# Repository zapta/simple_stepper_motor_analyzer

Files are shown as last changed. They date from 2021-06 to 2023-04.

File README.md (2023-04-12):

# Simple Stepper Motor Analyzer

**NOTE:** (April 2023) A new design of a stepper motor analyzer is available at 
https://github.com/zapta/ble_stepper_motor_analyzer. The new design has similar capabilities to this one but uses a Bluetooth link and a Mac/Windows/Linux app to display the data in real time. It is also less expensive to produce and can be ordered fully assembled from JLCPCB SMD service. You can embed one or more of the new analyzers in your 3D printer and connect to them remotely whever you want.

**NOTE:** (Aug 2022) A variant of the Simple Stepper Motor Analyzer can be purchased in Japan at 
https://nyarurato.booth.pm/items/4025304 . International shipping is also available.

**IMPORTANT:** We are not associated with any seller nor do we have any experience with their products
which may or may not differ from the design here. The Simple Stepper Motor Analyzer is an *as-is*
open source design for educational purposes and people may chose to use it on their own risk.

&nbsp;

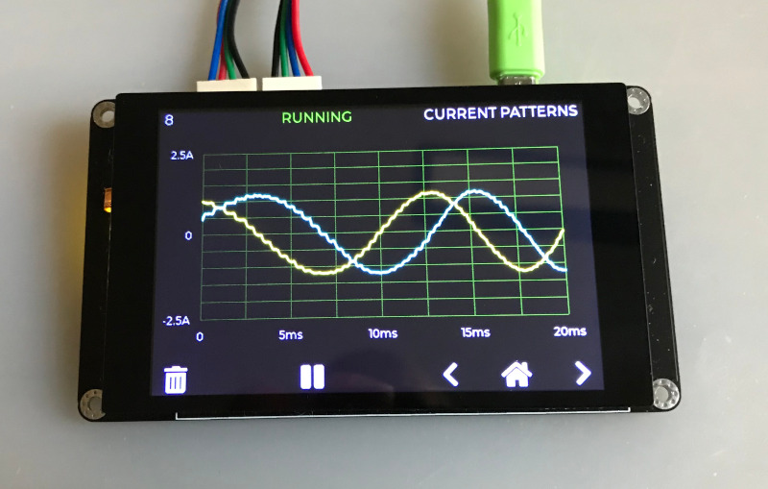
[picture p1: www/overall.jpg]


&nbsp;

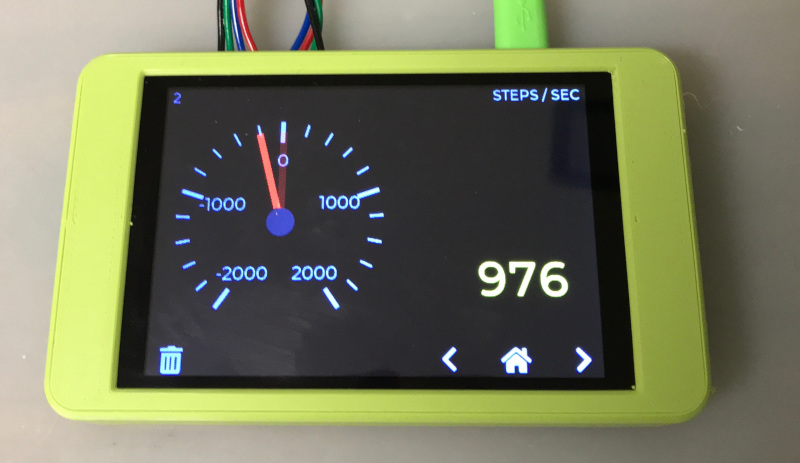
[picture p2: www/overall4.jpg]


&nbsp;

## Demonstration

Michael from the Teaching Tech youtube channel made [a great video explaining how stepper motors work](https://youtu.be/4iII25DGIdA) and used the Simple Stepper Motor Analyzer for some of the demonstrations. 

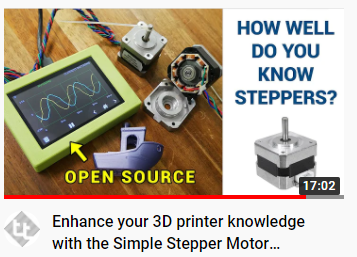
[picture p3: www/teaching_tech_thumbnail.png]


&nbsp;

## Highlights
* Low cost and minimalist DYI hardware design.
* Standalone. Doesn't require a computer to operate.
* Analyzes the stepper motor signals in the actual system (e.g. a 3D printer).
* Galvanically isolated current sensors. Does not interfere with the operating equipment, even when its turned off.
* Easy to connect using a pair 4 wire pass through connectors.
* Intuitive user interface with color display and a capacitive touch.
* Microstepping resolution of 1% of a full step.
* Provides momentary readings, signal patterns, and statistical measurements.
* Hardware and software are open sourced with a generous license.
* Based on free tools (Kicad, platformio, LVGL) and the Raspberry Pi Pico.
* Can be easily customized (new featured, cost reduction, data link to a computer, etc).
* Powered 5VDC, 200ma via a USB-C connector.

## Overview
Diagnosing the operation of stepper motor in 3D printers and CNC machines used to require stepper motor analyzers that costs thousands of dollar. Not anymore! The Simple Stepper Analyzer ('Analyzer' in short) brings these capabilities to every maker for a tiny fraction of the price and with a minimalist DIY electronic design that leaves the heavy lifting to the firmware.

The Analyzer is self contained, has two 4-wires pass-through connectors connecting the stepper motor, is powered from a common 5V charger with a micro USB cable, provides a simple to use graphical user interface with a 3.5" color touch screen, and provides a plethora of stepper motor measurements.

The Analyzer is provided to the community as a public domain reference design that can be built and used as is, or be customized with additional features or for a lower cost as desired. The hardware and firmware come with a liberal open source license (CC0) that allows commercial usages and doesn't require code source code sharing.

---
## Disclaimer
THE DESIGN IS PROVIDED "AS IS", WITHOUT WARRANTY OF ANY KIND, EXPRESS OR IMPLIED, INCLUDING BUT NOT LIMITED TO THE WARRANTIES OF MERCHANTABILITY, FITNESS FOR A PARTICULAR PURPOSE AND NONINFRINGEMENT. IN NO EVENT SHALL THE AUTHORS OR COPYRIGHT HOLDERS BE LIABLE FOR ANY CLAIM, DAMAGES OR OTHER LIABILITY, WHETHER IN AN ACTION OF CONTRACT, TORT OR OTHERWISE, ARISING FROM, OUT OF OR IN CONNECTION WITH THE DESIGN OR THE USE OR OTHER DEALINGS IN THE DESIGN.

---
## How does it work?
The principle of operation is very simple, and so is the hardware design. The stepper motor is connected via 4 wire pass-though connectors that allow the Analyzer to monitor the current through the stepper's coils. The Analyzer's user low impedance current sensors that are galvanically isolated such does not interfere with the operation of the 3D printer or other equipment it monitors. The Analyzer measures the coils currents 100k times a second and uses firmware that analyzes the data, extracts the desired measurements, and present them on the screen. For example, this is how an analysis of the distribution of distance by speed distribution looks like:

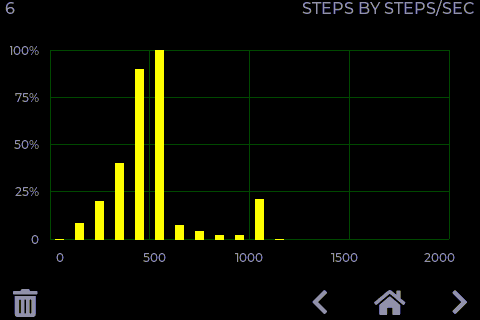
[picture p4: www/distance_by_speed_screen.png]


---
## Operation is simple and intuitive

1. Turn off power to the equipment (e.g. 3D printer).
2. Disconnect the 4 wires of the stepper motor and connect them through the Analyzer two pass through connectors.
3. Power the analyzer using a 5V charger and a micro USB cable.
4. Turn on the equipment and get the stepper going.
5. Use the Analyzer's screen to view the measurements you want.

**NOTE:** The two pass-through connectors of the Analyzer are symmetric and  each can act as an input or output. 

**CAUTION:** Always connect and disconnect stepper motors when their controller is not energized, to reduce the risk of damage to the controller due to high voltage spikes. The analyser itself is not subject to that risk since its uses galvanically isolated current sensors.

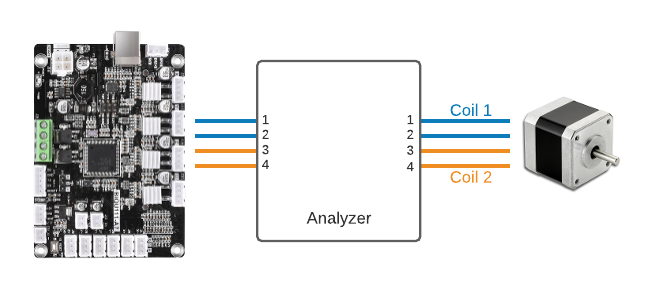
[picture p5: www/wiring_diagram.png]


**NOTE:** The only requirement for proper wiring is that the two wires of one coil should go through pins pair 1,2 and the two wires of the other coil should go through pin pair 3,4. The Analyzer doesn't care about the +/- polarity of the wires in each pair, nor does it care which of the two pass-through connectors is on the controller side and which one is on the stepper side.

**TRIVIA:**: The pin-out and the connector type of the Analyzer follows the Duet3D conventions, except that is uses right angle connector to save space.

---
## The Home Page
The Home page is first page shown when the Analyzer is powered on. It provides summary information as well as access to the Settings page.

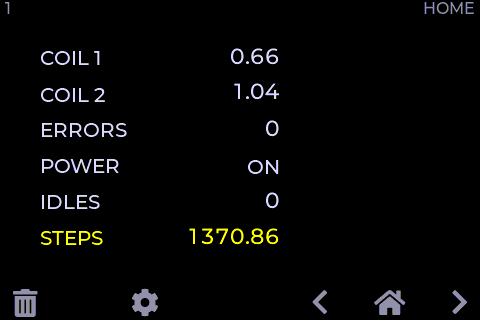
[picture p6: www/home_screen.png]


&nbsp;

#### Page Data

Field | Description
:------------ | :-------------
 COIL&nbsp;1 | Momentary coil 1 current in Amps.
 COIL&nbsp;2 | Momentary coil 2 current in Amps.
 ERRORS | The number of phase errors detected so far. Phase errors happens when the current patterns are so distorted that a forward/backward movement cannot be determined.
 POWER | Indicates if the stepper motor is currently energized. This is determined by the sum of currents in they two coils.
 IDLES | The number of times that stepper motor change status from energized to non energized.
 STEPS | The distance the stepper moved so far. Each full step forward increments this value by one and each full step backward decrements it by one. When the stepper motor is energized, the display also shows fractional steps in resolution of 1/100th of a full step.

HINT: The fractional step value cannot be reset because it is derived from the momentary currents in the two coils. Only the stepper motor driver can reset the fraction by positioning the stepper motor on an exact full step.

HINT: To swap forward/backward directions of the Analyzer use the Settings page. This does not affect the stepper motor itself.

&nbsp;
#### Page Actions

Action | Description
:------------: | :-------------
 | Clear all data.
 | Open the Settings page.

&nbsp;

---

## The Settings Page

This is a special page that is accessible from the Home page and allows to calibrate the Analyzer. The settings are stored in a non volatile memory and are preserved when the Analyzer is turned off.

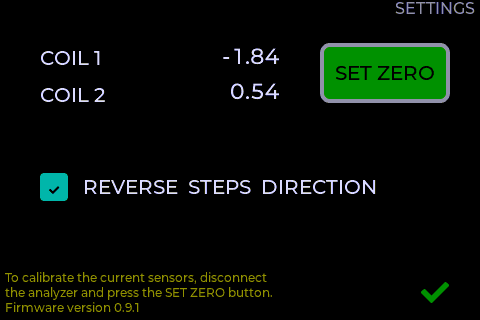
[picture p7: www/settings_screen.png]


&nbsp;
#### Page Data

Data | Description
:------------: | :-------------
COIL&nbsp;1 | The momentary current of stepper coil 1 in Amp units. Should be zero, or very close to zero, when the stepper motor is disconnected.
COIL&nbsp;2 | The momentary current of stepper coil 2 in Amp units. Should be zero, or very close to zero, when the stepper motor is disconnected.

&nbsp;
#### Page Actions

Action | Description
:------------: | :-------------
SET ZERO | Used to calibrate the zero reading of the current sensors. To do so, Disconnect the stepper motor and press this button.
REVERSE STEPS DIRECTION | Changes the forward/backward step directions of the Analyzer. Does not affect the stepper motor itself. Having the correct direction is important for measurements such as the Retraction analysis.
 | Press exist the Settings page.

&nbsp;

---

## The Speed Dial Page

This page measure the stepper speed in units of full steps per second. 

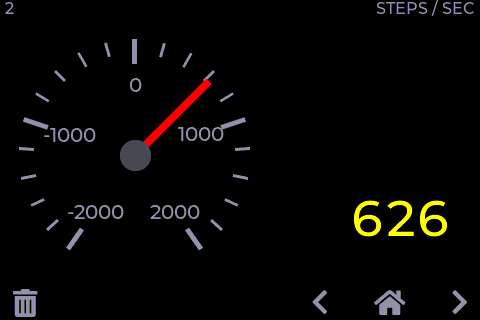
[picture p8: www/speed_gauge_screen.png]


&nbsp;
#### Page Data

Data | Description
:------------ | :-------------
Speed&nbsp;Dial | The speed dial shows the momentary stepper speed in full steps per second units. Forward speed is on the right side and backward speed is on the left.
Speed&nbsp;Value | This field shows the speed in a numeric form. IT is updated less frequently than the dial to allow easy reading.

&nbsp;
**HINT:** The Settings page allows to swap the forward/backward directions.

&nbsp;
#### Page Actions

Action | Description
:------------: | :-------------
 | Clears all data.
Tap the dial |Toggles the dial's speed range.

&nbsp;

---

## The Distance Graph Page

This page shows scrolling graph with the total number of full steps vs. time.

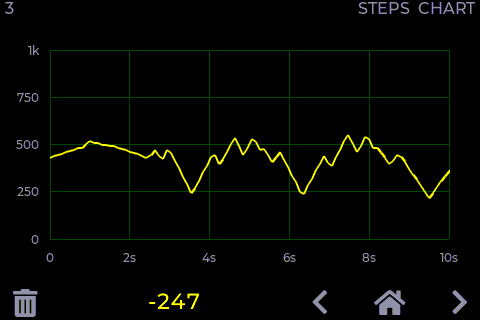
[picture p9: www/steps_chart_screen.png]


&nbsp;

#### Page Data

Data | Description
:------------ | :-------------
Distance&nbsp;Graph | This graph shows how the distance, in units of full steps, changes over time.
Distance&nbsp;value | The numeric value of the distance in full steps.  This fields is identical to the STEPS field in the Home page.

&nbsp;

#### Page Actions

Action | Description
:------------: | :-------------
 | Clears all data.
Tap the graph | Toggles the range of the vertical axis.

&nbsp;

---

#### The Retraction Graph Page

This page is useful to analyze the retraction in of 3D printer extruder.

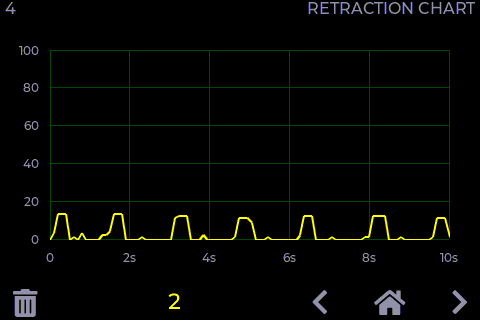
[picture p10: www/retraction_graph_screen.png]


&nbsp;
**TRIVIA:** The graph above was taken while testing a direct extruder printer with [Thing #909901](https://www.thingiverse.com/thing:909901).
&nbsp;
#### Page Data

Data | Description
:------------ | :-------------
Retraction&nbsp;Graph | This graphs tracks the retraction of 3D extruder full step units.  Retraction is defined as the filament length that was inside the extruder and is now retracted outside of the extruder. 
Retraction value |  This field shows the current retraction level in a numeric form.

&nbsp;
#### Page Actions

Action | Description
:------------: | :-------------
 | Clear all data.
Tap the graph | Changes the range of the vertical axis.

&nbsp;

---

## The Time by Speed Page

This page shows an histogram with the distributing of time by stepper speed. That is how much time was spent in each speed range. The values are normalized such that the longest bar is always at 100%.

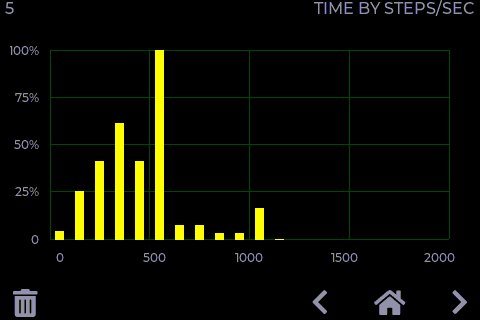
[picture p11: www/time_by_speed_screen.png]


&nbsp;
#### Page Data

Data | Description
:------------ | :-------------
Time&nbsp;Histogram | The horizontal axis indicates speed in full steps per second units. The height of each bar indicate the time of all steps in that speed range, with the length of the longest bar normalized to 100%.

&nbsp;
#### Page Actions

Action | Description
:------------: | :-------------
 | Clear all data.

&nbsp;

---

## The Distance by Speed Page

This page shows an histogram with the the distribution of distance by stepper speed.



&nbsp;
#### Page Data

Data | Description
:------------ | :-------------
Distance&nbsp;Histogram |  The horizontal axis indicates speed in full steps per second units. The height of each bar indicate the distance or number of steps in that speed range, with the length of the longest bar normalized to 100%.

&nbsp;
#### Page Actions

Action | Description
:------------: | :-------------
 | Clear all data.

&nbsp;

---

## The Current by Speed Page

This page measures the ability of the stepper motor's controller to maintain peak current at high speeds.

The screenshot below shows a healthy system where the peak current is virtually flat across the speed range.

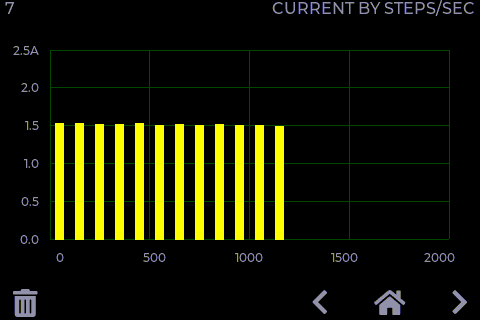
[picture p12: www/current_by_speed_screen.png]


The screenshot below shows a system that is not capable to maintain peak current and starves the stepper motor at high speeds, resulting in poor torque and possible skipped steps.

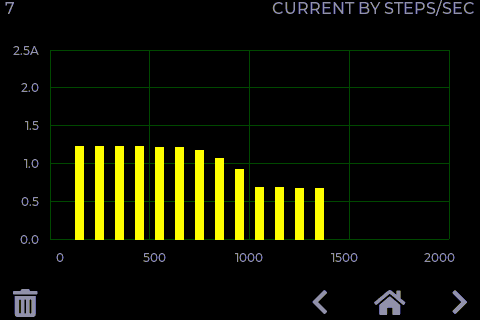
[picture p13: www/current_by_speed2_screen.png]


&nbsp;
#### Page Data

Data | Description
:------------ | :-------------
Peak&nbsp;Current&nbsp;Histogram | The horizontal axis indicates speed in full steps per second units. The height of each bar indicates the average peak current in Amps of  steps that speed range. 

&nbsp;
#### Page Actions

Action | Description
:------------: | :-------------
 | Clear all data.

&nbsp;

---

## Coil Current Patterns Page

This page shows the current patterns in the two stepper coils.

The screenshot below shows a healthy system where the signals are nice and clean and reaches the target peak current.

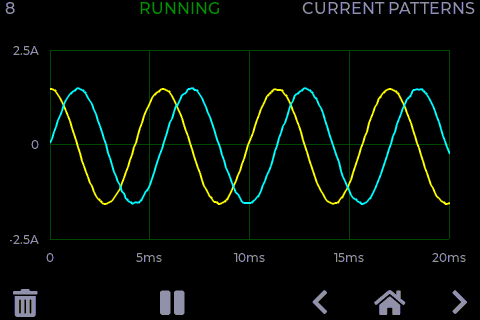
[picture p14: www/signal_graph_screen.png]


&nbsp;

The screenshot below is from a poor system where high speed results in distorted and insufficient current, resulting in loss of torque and a potential for skipped steps.

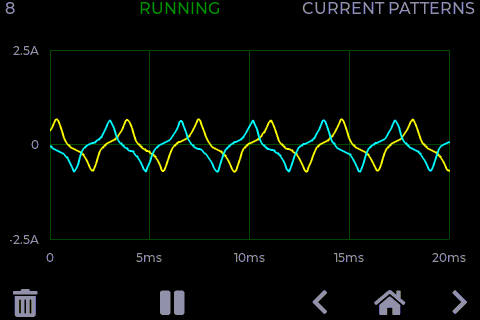
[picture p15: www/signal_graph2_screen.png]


&nbsp;

**GENERAL INFORMATION:** Each cycle of the stepper current pattern represent 4 full steps. The centers of those steps are at on the four vertical dotted lines where the currents of the two coils are identical, in the same or in  opposite polarities. The transitions between the steps are on the 4 vertical solid lines where one of the coils is at zero current. This cycle of 4 full steps is sometimes referred to as a single 'electric rotation'. The analyzer computes the exact phase on this cycle using the standard trigonometric function atan2(current1, current2) which can also be calculated manually from the current readings in the Home page.

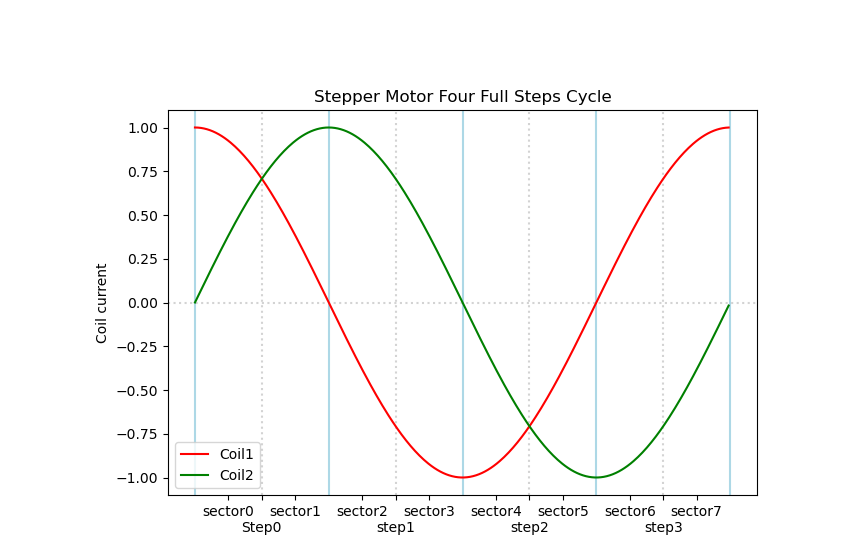
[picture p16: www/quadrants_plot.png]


&nbsp;

#### Page Data

Data | Description
:------------ | :-------------
Current&nbsp;graph | The horizontal axis indicates time in milliseconds. The vertical axis indicate coil current level in Amps. The two graphs show the current patterns of the respective stepper coils.

**NOTE:** The graph is updated only when sufficient stepper motor movement is detected.

&nbsp;
#### Page Actions

Action | Description
:------------: | :-------------
 | Clear all data.
 | When running, pauses the display updates.
 | When paused, resume the display updates.
Tap the graph | This toggles the range of the horizontal axis.

&nbsp;

---

## Coil Current Phase Page

This page draws the current patterns of the two coils as a [Lissajous curve](https://en.wikipedia.org/wiki/Lissajous_curve) which allows to examine visually distortions such as non sinusoidal current, phase distortion, and reduced amplitude.

In an ideal system, the graph is a perfect smooth circle, that doesn't change its size when the stepper's speed changes. Patterns that significantly diverge from that indicates a sub optimal configuration and operation.

Following picture shows a pattern from a well functioning system. The graph is round, reasonable smooth, and has sufficient size which indicates good current drive. 

The horizontal axis indicates the coil 1 current and the vertical axis indicates coil 2 current. In this example, both span nicely between -2A to +2A.

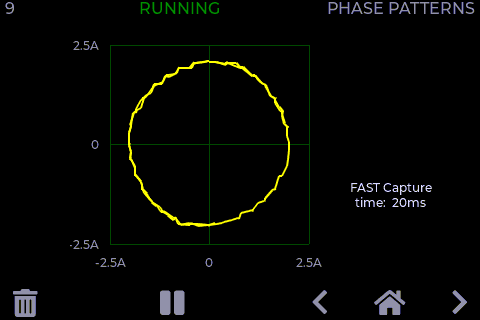
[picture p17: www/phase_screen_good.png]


&nbsp;

The screenshot below is from a poor system where high speed results in distorted and insufficient current, resulting in loss of torque and a potential for skipped steps. The pattern is far from a clean circle and the shape has reduced size.

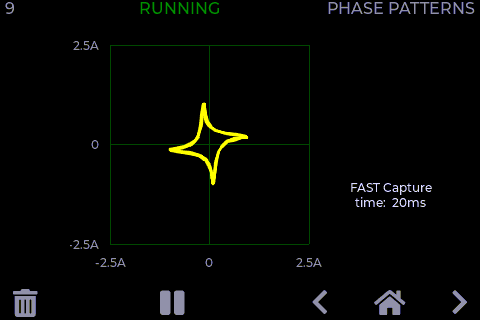
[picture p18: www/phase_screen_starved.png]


&nbsp;

The screenshot below shows a sub optimal operation where a a speed increase of the stepper results in small (less current and torque) and even more distorted curve.

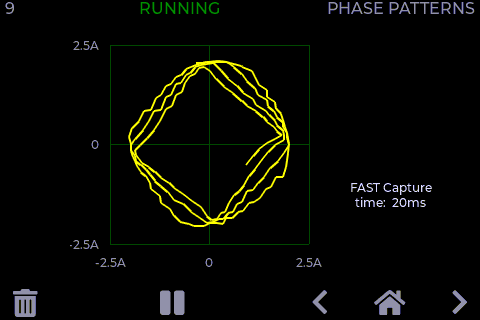
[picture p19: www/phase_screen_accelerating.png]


&nbsp;

The screenshot below shows a well functioning system. The smaller size of the circle compare to the example above indicates that it operates on lower current.

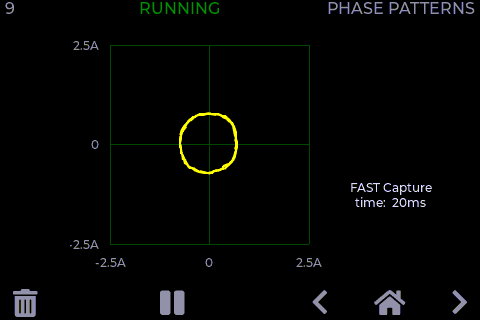
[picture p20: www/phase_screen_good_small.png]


&nbsp;

The screenshot below show an operation of a stepper in full steps mode. The dimension of the pattern indicate good current feed, and the square  shape is the best a full step driver can deliver.

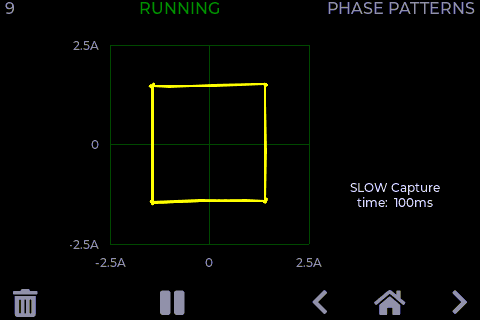
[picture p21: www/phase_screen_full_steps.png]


&nbsp;

The screenshot below show an operation of a stepper in half steps mode. The dimension of the pattern indicate good current feed, and the shape is somewhere between the square shape of full step mode and the round shape of micro stepping interpolation mode.

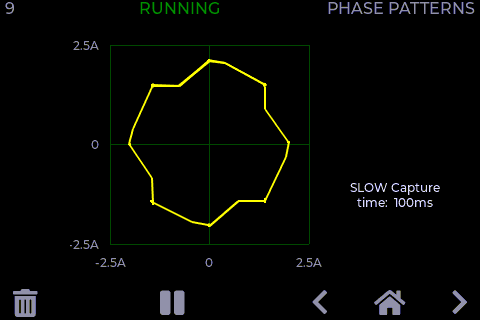
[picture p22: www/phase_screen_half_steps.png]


&nbsp;

#### Page Data

Data | Description
:------------ | :-------------
Lissajous&nbsp;curve | A Lissajous curve drawn from the current pattern of coil 1 (x) and coil2(y). 
Capture speed | Shows the signal capture time. Fast mode works better with fast moving steppers and slow mode works with slow moving steppers. Tap the graph to toggle.

**NOTES** 
* The graph is updated only when sufficient stepper motor movement is detected.
* To view the current pattern that resulted in the current phase pattern, use the navigation button to switch the current patters page, and vice versa.

&nbsp;
#### Page Actions

Action | Description
:------------: | :-------------
 | Clear all data.
 | When running, pauses the display updates.
 | When paused, resume the display updates.
Tap the graph | This toggles the capture time between fast and slow speeds.

&nbsp;

---

## Reference Design Specification

Item | Specification
:------------ | :------------- 
Power consumption | 5V, 175ma.
Power connector | micro USB
MCU | Raspberry Pi RP2040 (Pico module).
Flashing | Drag and drop to a virtual disk.
Data link | USB/Serial link available but not used.
Current measurement | +/-2.5A per coil. (+/-5A sensors optional).
PCB | 102mm x 57mm, two layers
Enclosure | 3D printed, 108.4mm x 63.4mm x 16.6mm
Display | 3.5" 480 x 320, Color, Landscape mode.
Touch screen | Capacitive
Sensor isolation | See ACS70331 data sheet
Sampling rate | 100Khz per channel.
Sampling resolution | 12bits
Current accuracy | estimated at +/- 1%
Max step rate | Software dependent. Currently 2K full steps/sec.
Step resolution | 1/100th of a full step.
User settings storage | On board FLASH.
GUI framework | LVGL library. R3G3B2 color depth.
Programming language | C++
Programming IDE | VSCode, Platformio, WizIO.
Electronic design software | Kicad.
Mechanical design software | Onshape. 

&nbsp;

---

## I want to build me one

The electronic schematic, PCB layout, gerber files, and the firmware source files and released binary are all available on this github repository.

[Schematic](./kicad/stepper_analyzer.pdf)

[Production files](./kicad/JLCPCB)

[BOM](./kicad/BOM.xlsx)

&nbsp;

**Instructions:** Order the PCB with JLCPB with SMD service (see JLCPCB directory with gerbers and bom and pos files). Attach the Pico with XFasten tape and solder. Cut the bottom pins of the KF2510 connectors to 1mm length and solder from the top of the PCB only. Solder the current sensors, attach the TFT to the back of the PCB with XFasten tape and carefully connect the two FPC cables. Program the Pico by connecting it to a computer while it's bootsel button is pressed and drag he uf2 release file to the virtual disk you will see on your computer.

Note: The two servo connectors may be hard to insert and remove due to a small bump on the male side that is intended to lock in place the female connector. If you are handy with X-Acto knife, you can try carefully scraping that bump for easier insertion as I did (knives are sharp and may be dangarous, use proper precautions). 

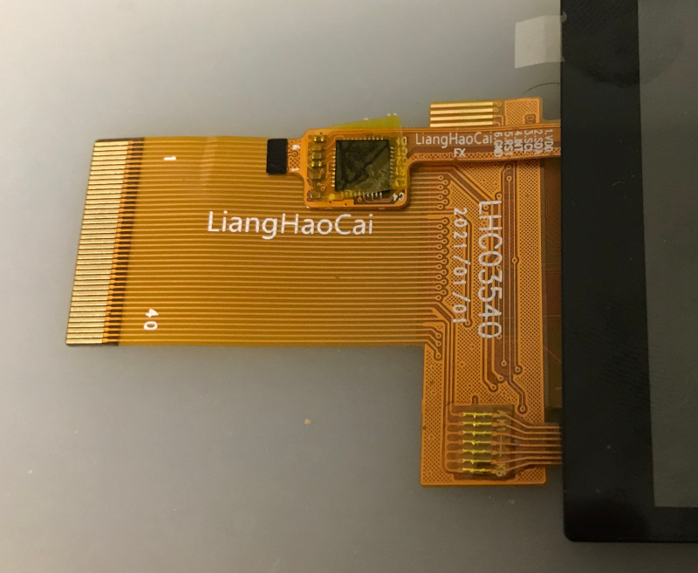
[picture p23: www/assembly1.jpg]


&nbsp;

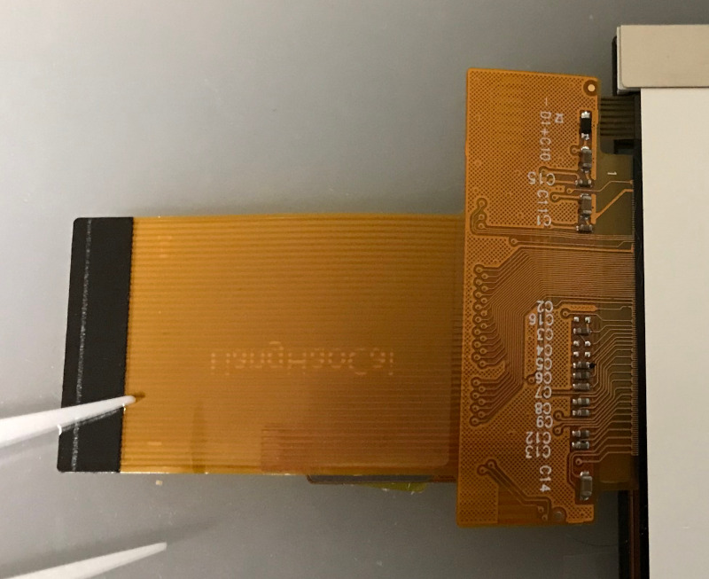
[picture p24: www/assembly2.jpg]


&nbsp;

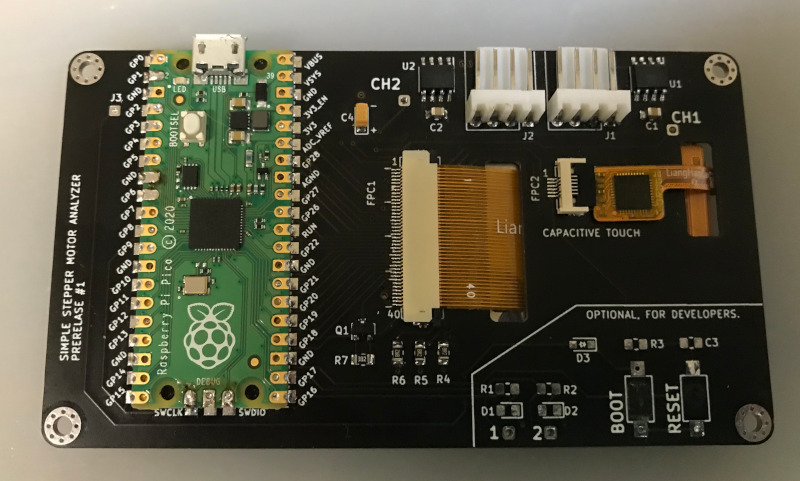
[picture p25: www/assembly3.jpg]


&nbsp;

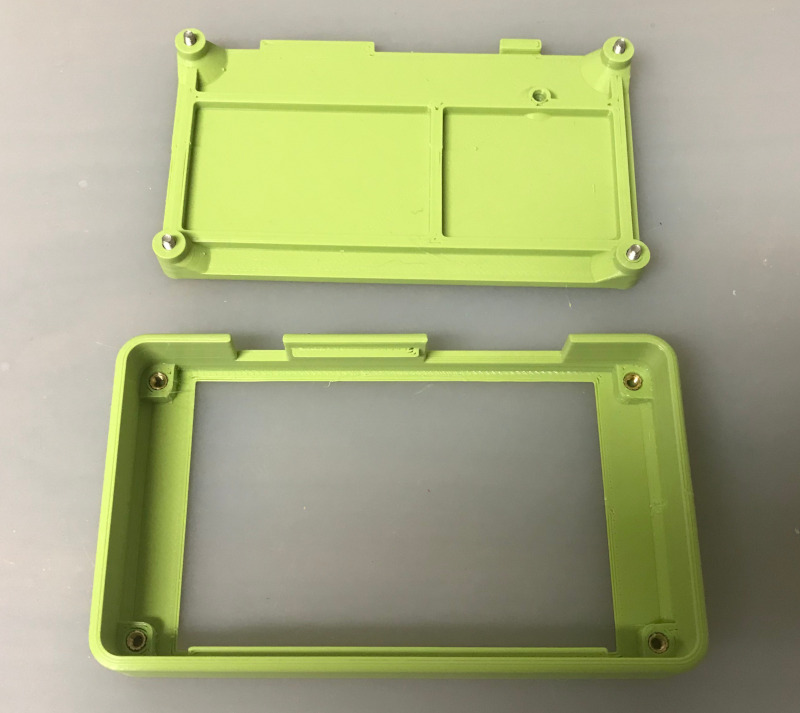
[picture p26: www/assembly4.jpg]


&nbsp;

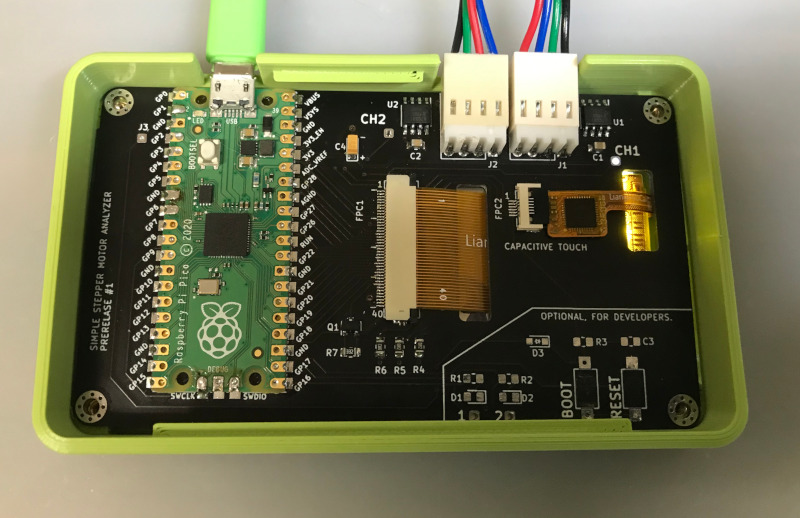
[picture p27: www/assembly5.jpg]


## Mechanical
3D print the two part of the enclosure (STL files in this github repository), insert the four M2.5x3.5x3 heated inserts with a solder iron, drill the four  2.5 holes in the cover, insert the PCB to the front part, make sure the TFT seats flush with front and secure the back with four M2.5x10 hex cup screws.

## Ideas for improvements
The Analyzer is provided as a fully functional reference design and changes and the developers encourage improvement/modifications of the hardware and/or firmware are encouraged. This can include new features, new measurements and pages, extending the design to support 2 or 3 steppers at once to track the x/y/z of a 3D printer, reducing the hardware cost using less expensive screen TFT, or even eliminating the screen altogether and using the Analyzer as a dongle tethered to a computer via the existing USB/Serial link.

&nbsp;

---

## FAQ

#### Q: Can I buy from you a few units?

A: We cannot provide assembled units for the general public. For that reason, we released the design with CC Zero license with the hope that other entrepreneurs will do so.

#### Q: Where do you source the TFT panels?

A: We buy the '3.5 LCD CTP' variant here https://www.aliexpress.com/item/32862869103.html. The choice of TFT panel and the mechanical design of the PCB follows Dustin Watts' ESP32 Touchdown project https://www.tindie.com/products/dustinwattsnl/esp32-touchdown/ (with extra 2mm to the PCB's length for extra clearance for the threaded heat inserts).

#### Q: Can the firmware of the analyzer be updated?

A: Yes. New firmware is released as .uf2 files. To flash the analyzer with a compatible .uf2 follow the standard procedure of the Raspberry Pi Pico. Access to the BOTSEL button is provided by a hole at the back of the 3D printed enclosure.

#### Q: Why some footprints on the PCB are not populated?

A: The PCB design includes circuitry that helps developing firmware for the analyzer that is not necessary or helpful for normal opeation of the analyzer.

#### Q: Can the current scale of the two channels increased from +/-2.5A?

A: The PCB was designed to accept also +/-5A variants of the current sensors and the optionals resistors R8 R9 were added to allow configuring the firmware to know about the larger current scale. This however was not tried yet since most 3D printer steppers do not exceed currents of 2.5A.

#### Q: Why not a SPI based TFT?

A: We could not achieve fast enough display refresh rate with SPI so switched to 16 bit parallel data transfers. With the optimized firmware we can update rate equivalent to 200Mhz SPI. 

#### Q: Can a cheaper TFT/touch be used?
A: Yes, but it will require design changes.

#### Q: Can the TFT screen be eliminated?
A: Yes. The Analyzer has a USB/Serial output can a small Analyzer dongle can communicate with a computer program. This will require firmware changes.

#### Q: Can you add feature X or customization Y?

A: Most likely not. The reference design is provided for the community to change and mix.

#### Q: I want to commercialize or crowd source it, can you help me?

A: Not really. The reference design is open source and you will need to find others to help you. We don't mind though to answer questions.

#### Q: Where do I file a bug?

A: Use the github repository.

#### Q: Is it ok to connect/disconnect power to the Analyzer while my 3D printer prints?

A: Of course. The Analyzer is isolated from the stepper wires and should not interfere with the operation of the printer.

#### Q: The Analyzer uses LVGL lib, what is the license of that library?

A: At the time of writing this, the LVGL license is available here https://github.com/lvgl/lvgl/blob/master/LICENCE.txt.  The Analyzer's developers are not affiliated with LVGL.

#### Q: Is the LVGL library included in the Analyzer's repository?

A: It's not needed. LVGL is supported by platform.io so the Analyzer's project is set for platform.io to fetch LVGL automatically.

#### Q: Can the firmware be built with the standard Raspberry Pi Pico C++ SDK?

A: It should be but we didn't try it. Installing the SDK, libraries and tools using platformio and the WizIO Pico 'baremetal' distribution is easier.

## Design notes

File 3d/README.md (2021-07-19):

The enclosure models are available on Onshape for viewing, editing and exporting.
Printing with PLA+ may provide better strength than regular PLA.

** Variant 1 (Easier) - self tapping plastic threads. Easier to source.
Screws: Hex socket head cap, M2.5 x 10mm.  https://www.aliexpress.com/item/10000139502321.html
https://cad.onshape.com/documents/58d3fc7e6c256c4f6a684caf/v/919d1c8c2464819c6bc56821/e/96371cb25b019416be0a198b

** Variant 2 - metal threaded heat inserts
Heat threaded inserts: M2.5, 3.5mm OD, 3mm length.  https://www.aliexpress.com/item/4000688982018.html
Screws: Hex socket head cap, M2.5 x 10mm.  https://www.aliexpress.com/item/10000139502321.html
https://cad.onshape.com/documents/58d3fc7e6c256c4f6a684caf/v/9748de4b75ec777ad8fbd9ed/e/96371cb25b019416be0a198b

Important: Clean the 3D print to have a clean and flat surface for the TFT front surface interface.

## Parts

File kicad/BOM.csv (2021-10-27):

Ref | Quantity | Value | Footprint | JLCPCB Service | Comments
C1, C2, | 2 | Ceramic capacitor 100nf | SMD 0805 | Yes
C3, | 1 | Ceramic capacitor 10uf | SMD 0805 | Yes
FPC1, | 1 | FPC connector 40 pins, 0.5mm pitch TOP contacts. |  | Yes | LCSC C11097 or similar.
FPC2, | 1 | FPC connector 6 pins, 0.5mm pitch BOTTOM contacts. |  | Yes | LCSC C262262 or similar
Q1, | 1 | N-Chan MOSFET AO3400A | SOT-23 | Yes
R1, R2, R3, | 3 | Resistor 8.2 Ohms | SMD 0805 | Yes
PCB | 1 | Custom PCB per gerber files |  | Yes
J1, J2, | 2 | Right angle connector, 4 pins, 0.1” pitch. KF2510 |  | No | AliExpress. Trim pins using the 3D printed jig, BEFORE soldering them.
U1, U2, | 2 | ACS70331EOLCTR-2P5B3 | SOIC-8 | No | AliExpress
U3, | 1 | Raspberry Pi Pico |  | No
TFT | 1 | TFT module 3.5” 320x480, IL9488, capacitive touch FT6206 |  | No | AliExpress JR E-Shop, “3.5 LCD CTP”
Threaded heat Inserts | 4 | M2.5 x 3.5mm OD x 3mm length |  | No | AliExpress Centrode Store
Screws | 4 | M2.5 x 10mm, hex cup head. |  | No | AliExpress
Enclosure | 1 | Use provided 3D model |  | No
Tape |  | Double sided thermal tape 10mm width, 0.2mm thickness |  |  | AliExpress

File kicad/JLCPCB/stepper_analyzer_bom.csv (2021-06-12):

Comment | Designator | Footprint | LCSC Part Number
100nf ceramic | C1,C2 | SMD 0805 | C49678
10u ceramic | C3 | SMD 0805 | C15850
FPC connector 40pins, 0.5mm, TOP contacts | FPC1 | FH12-40S-0.5SH_1x40-1MP_P0.50mm_Horizontal_flipped | C11097
FPC connector, 6 pins, 0.5mm, BOTTOM contacts | FPC2 | FH12-6S-0.5SH_1x06-1MP_P0.50mm_Horizontal | C262262
AO3400A | Q1 | SOT-23 | C20917
8.2 Ohm | R1,R2,R3 | SMD 0805 | C25330

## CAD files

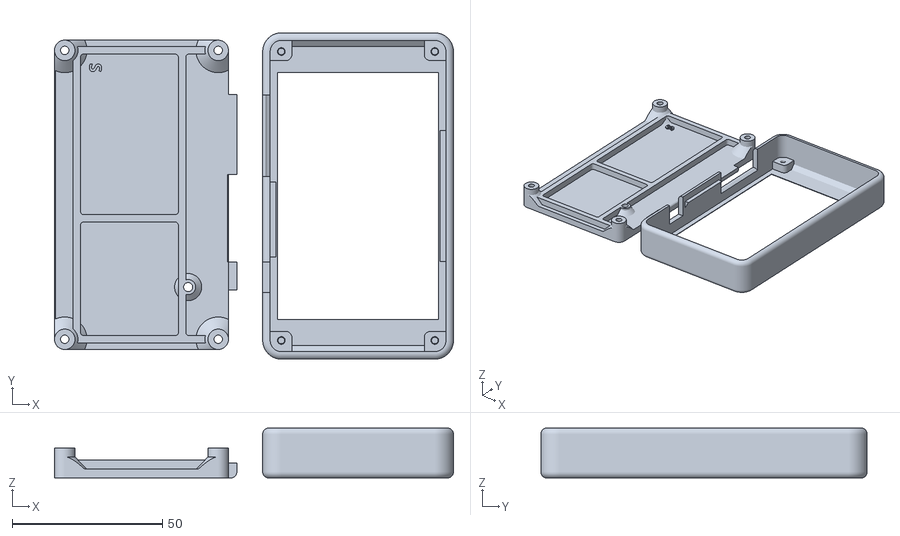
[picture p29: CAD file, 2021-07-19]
3d/enclosure_self_tapping_threads.stl
132.6 x 108.4 x 16.6

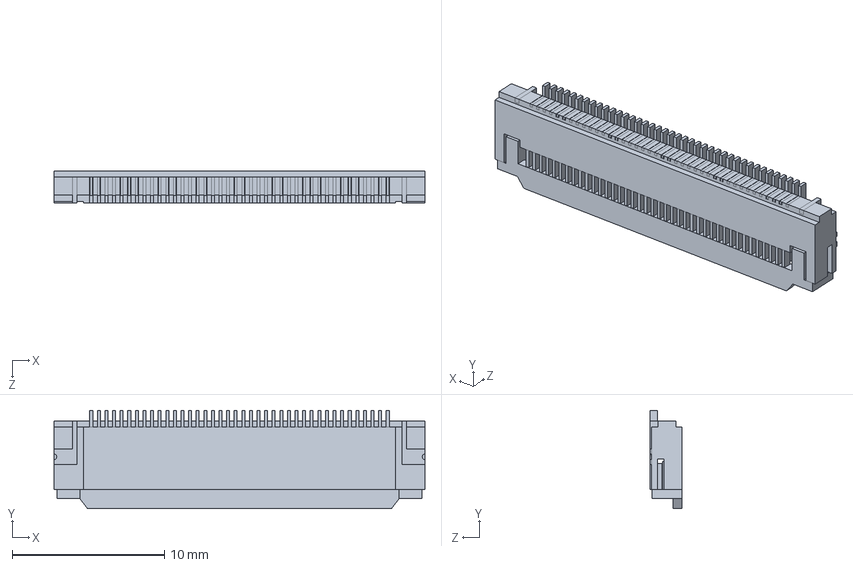
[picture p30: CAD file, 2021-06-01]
kicad/models/Peça2.SLDPRT
24.4 x 6.45 x 2.13 mm

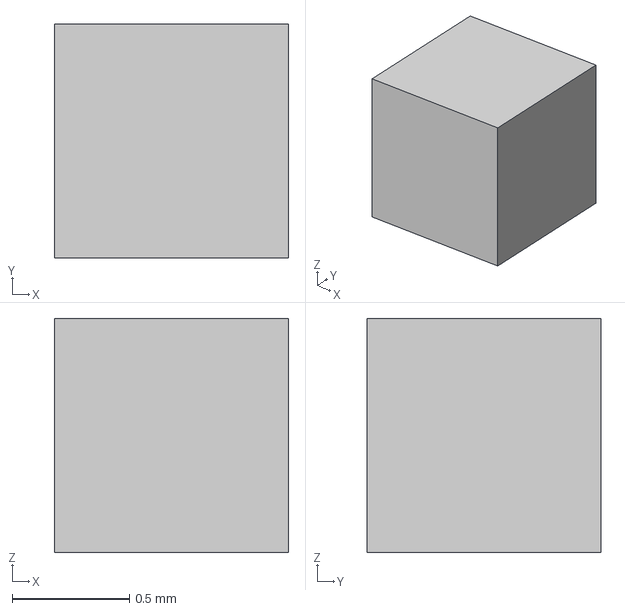
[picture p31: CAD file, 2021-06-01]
kicad/models/unit_cube.step
1.00 x 1.00 x 1.00 mm

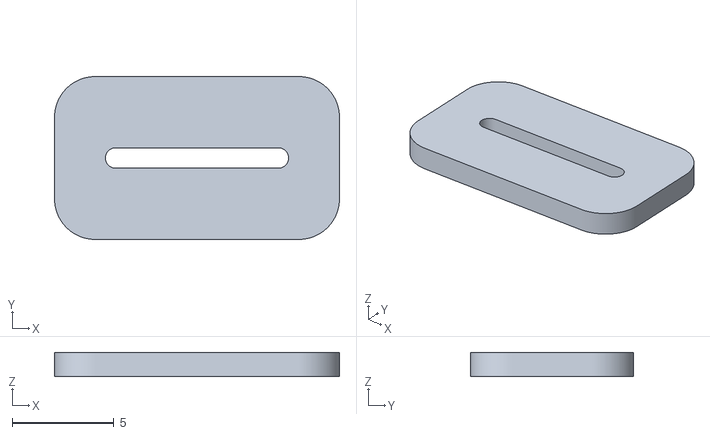
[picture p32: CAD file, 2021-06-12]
3d/connector_trim_jig.stl
14.0 x 8.00 x 1.20

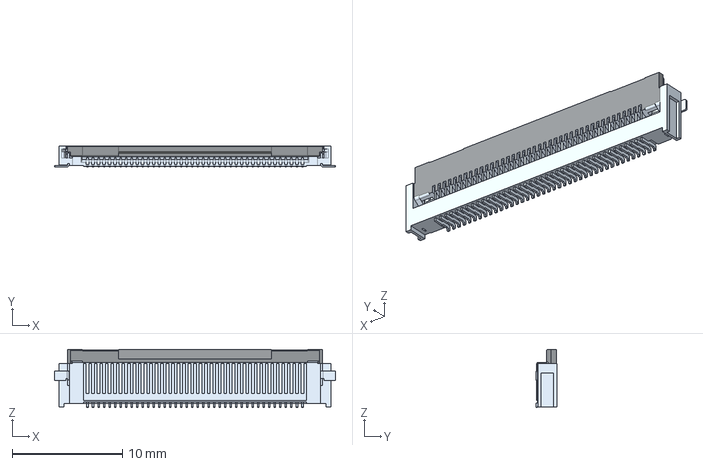
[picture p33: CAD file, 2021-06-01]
kicad/models/molex_fpc_40_05_5051104091.step
25.5 x 1.90 x 5.30 mm

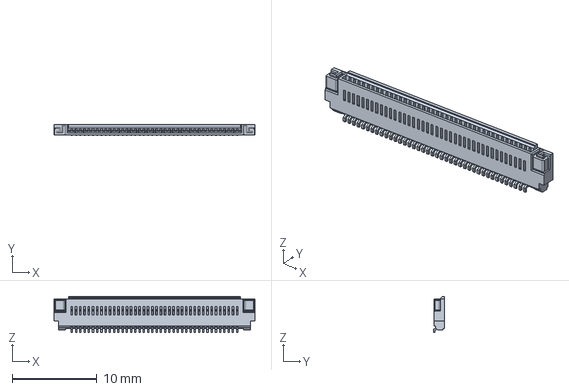
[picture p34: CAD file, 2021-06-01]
kicad/models/molex_fpc_40_512964033.stp
23.7 x 1.30 x 4.30 mm

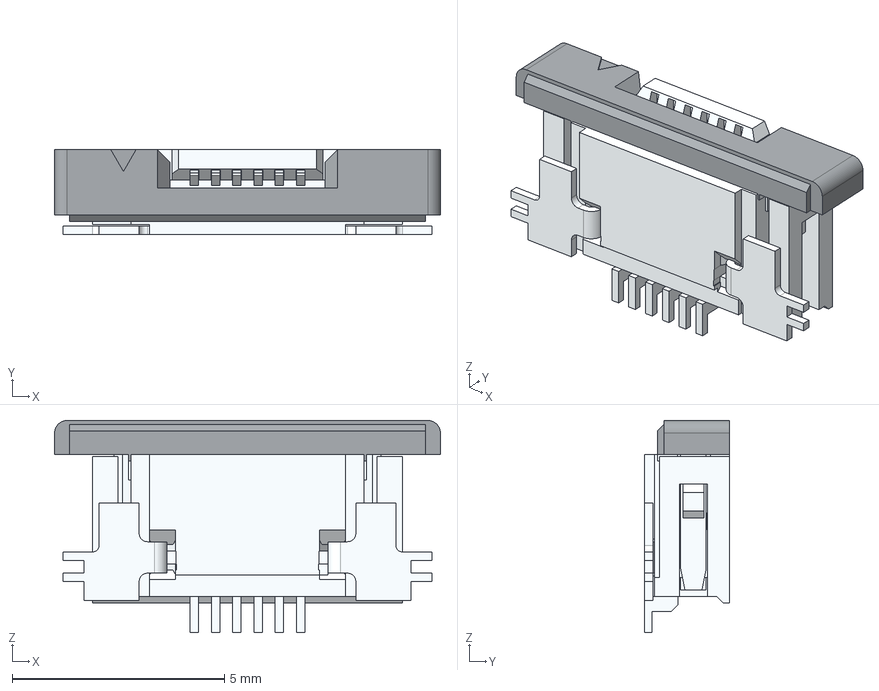
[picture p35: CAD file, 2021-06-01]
kicad/models/molex_fpc_6_05_527450633.step
9.10 x 2.01 x 5.00 mm

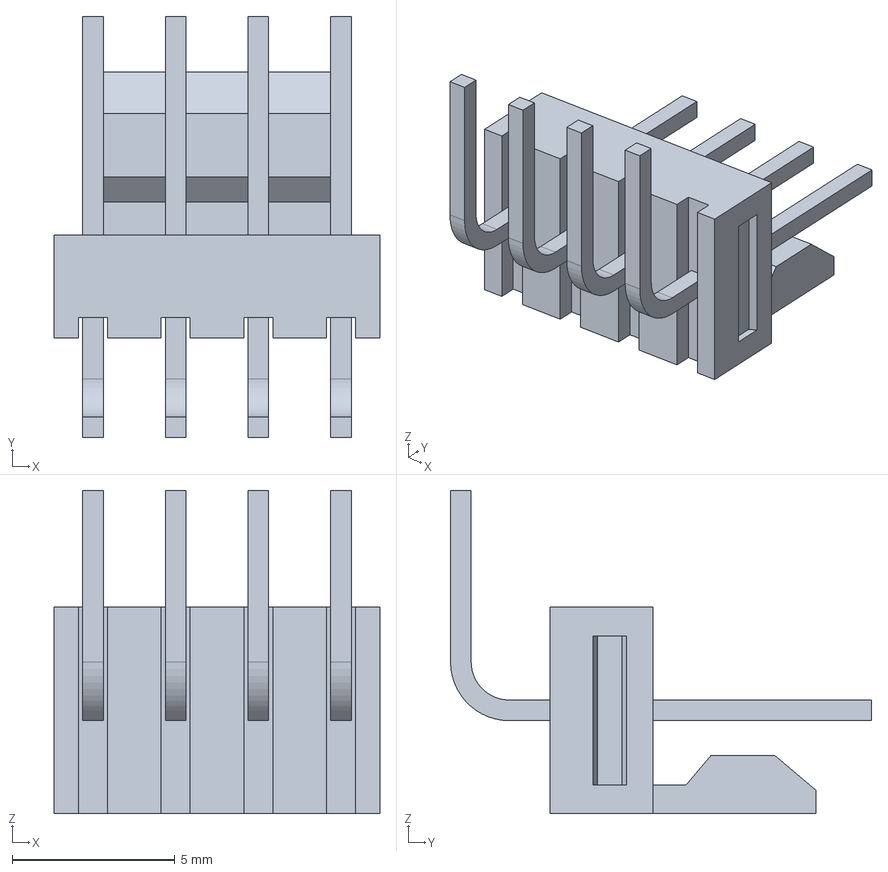
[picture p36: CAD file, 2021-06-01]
kicad/models/molex_kk_4pins_right_angle_022053041.stp
10.0 x 12.9 x 9.93 mm

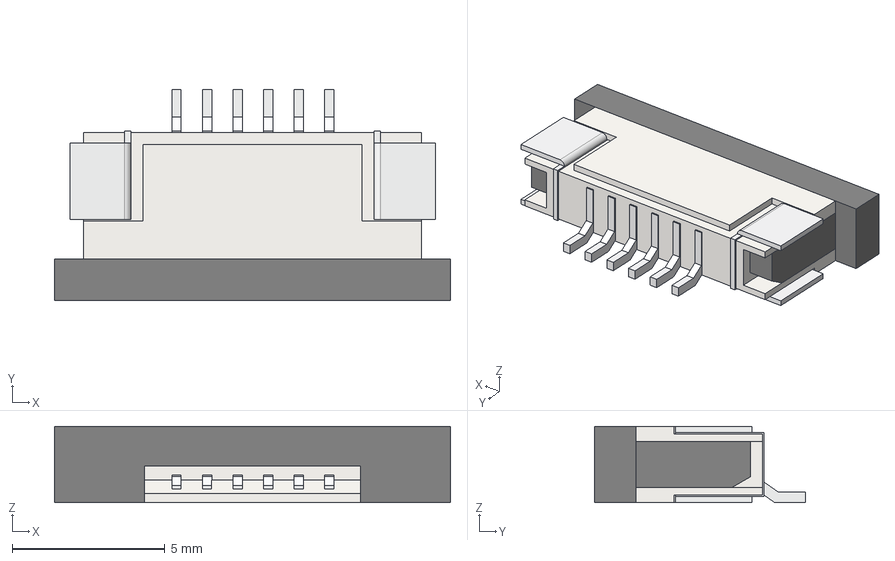
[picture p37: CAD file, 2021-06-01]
kicad/models/FPC 6-PIN SMD.stp
13.0 x 6.90 x 2.50 mm

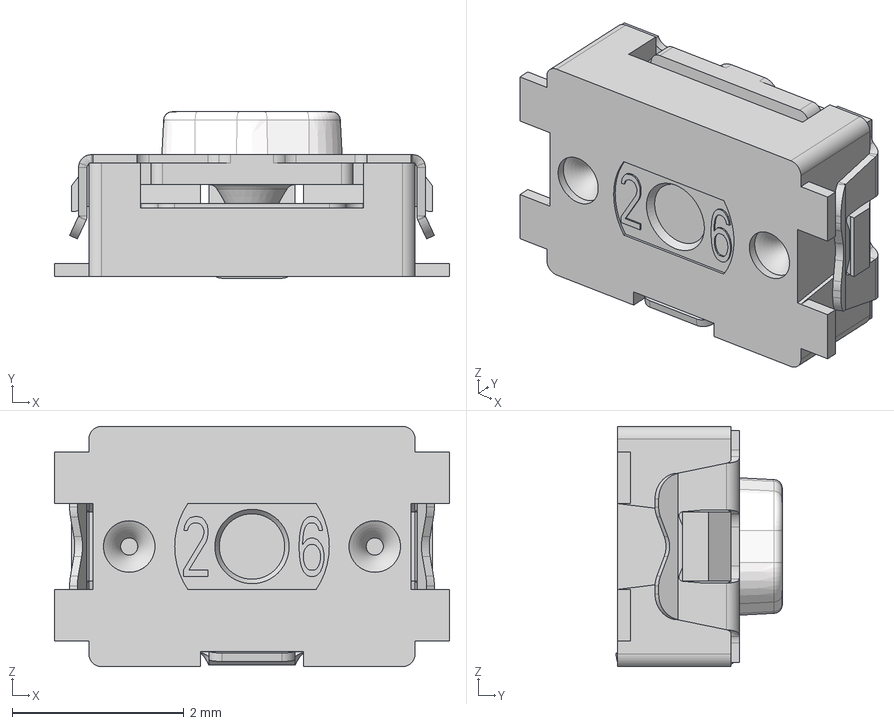
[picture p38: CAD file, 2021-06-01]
kicad/models/KMR211GLFS.step
4.60 x 1.94 x 2.80 mm

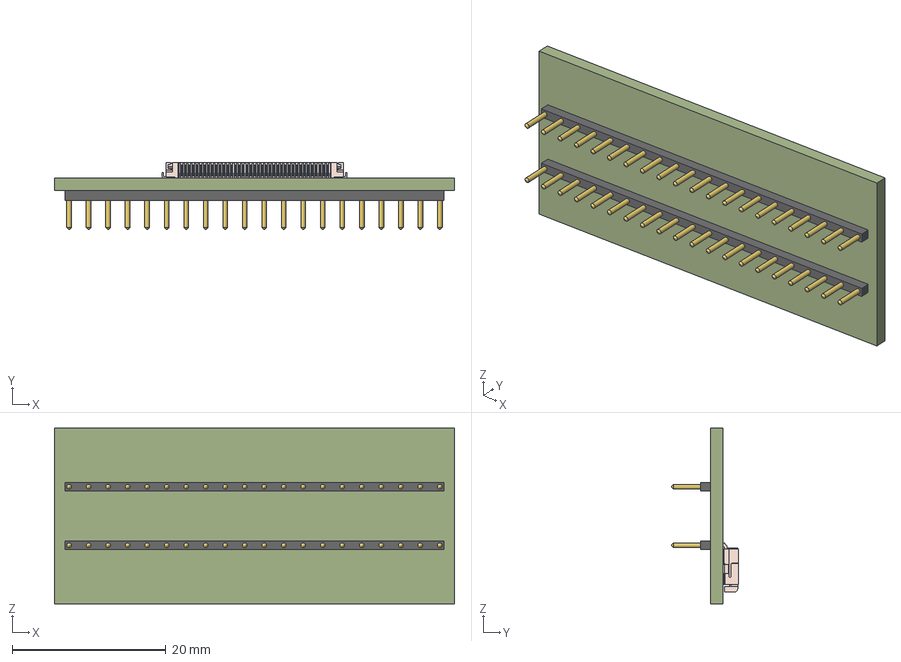
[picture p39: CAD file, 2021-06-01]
kicad/models/FH12-40S-0.5SH.stp
52.1 x 8.73 x 22.9 mm
FPC050P040 Breakout Board
FH12-40S-0.5SH(55)

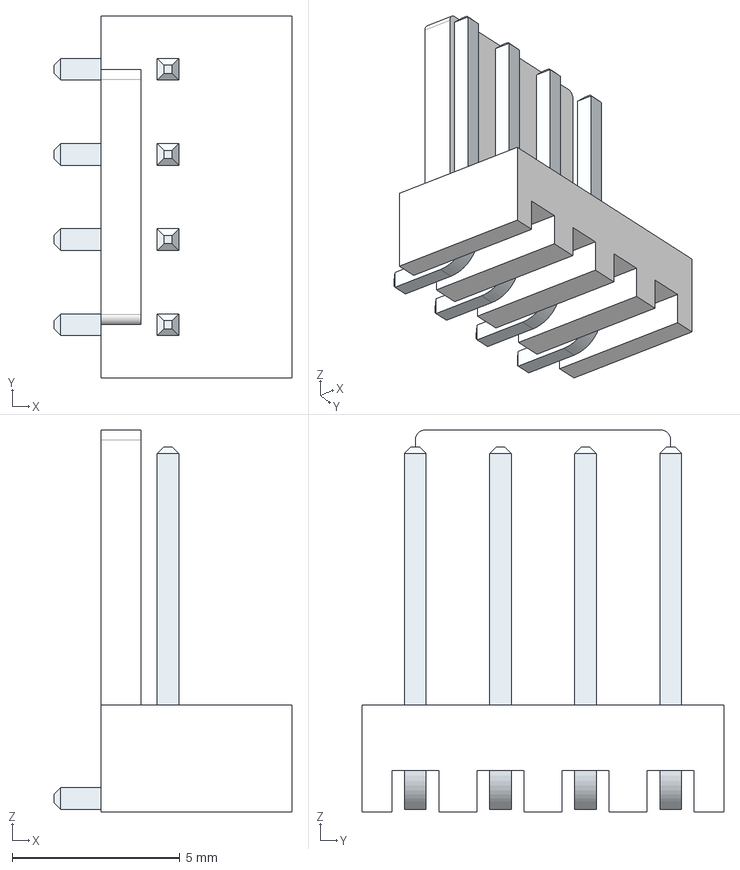
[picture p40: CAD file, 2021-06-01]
kicad/models/kf2510_4p_right_angle.step
7.10 x 10.8 x 11.4 mm

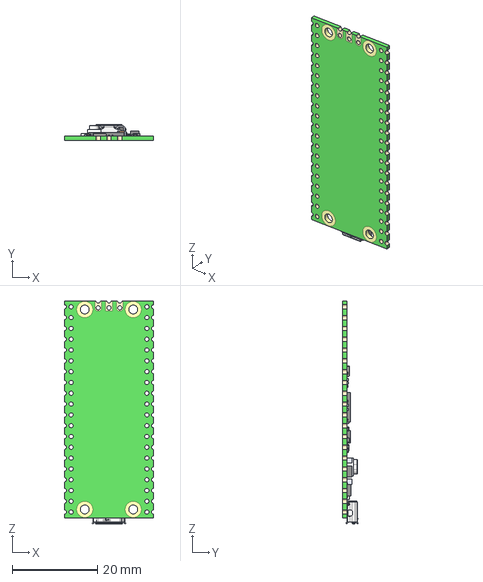
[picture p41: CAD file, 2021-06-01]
kicad/models/pico.step
21.0 x 3.69 x 52.4 mm

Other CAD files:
3d/enclosure_metal_insert_threads.stl
kicad/models/KMR211GLFS.stp

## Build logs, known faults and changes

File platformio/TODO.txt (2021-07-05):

* Consider to add an animation on screen transition (anonying?)

* Switch to Pico SDK 1.2.x

* Switch to LVGL 8.

============= DONE

* Add backlight control slider (UI).

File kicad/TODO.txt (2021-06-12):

Replace 10u tantalum with cermaic (cost)

* Delete junk kicad and model files.

----- Done

* Verify drill size of Molex pins

* Add a way to configure current range. E.g. via resistor.

* Increase horizontal clerance for the four screws. (extend the PCB).

* Reduce diameter of vias in ground pads of the pico

* Update instruction silk messages on the PCB (e.g. tape thickness)

* Verify sufficient clearance at the sides of the TFT, for buttons and LEDs.

* Make the LED footprint compatible with 0603 and 0805 LEDs.

* Clearer mark for pin 1 of the current sensors. E.g. a dot.

* Change the order of FPC 6 pins, to match the flat cable

* Add F-Silk marks with the stepper connector pin lables (A1, A2, ...)

* Move the Molex connector to be at 50 mill relative pitch

* Finalize BOM.

* Finalize the choice of connectors

* Smaller holes for the MOLEX connectors?

* MOSFET footprint too small?

* Smaller holes for the ground pads of the Pico?

* Move the BOOTSEL pad closer to the Pico's switch.

* Remove SWD pads from the PCB

* Diode footprint too small ?

* Lower profile switches

* Move the Molex connectors slightly out?

* Move LED 1,2 test points to the front of the board.

* Add duplicate leds on the front of the board.

* Review through holes

* Add a silkscreen text below the Pico to place Kapton tape here.

* Is the pullup resistor of the BOOT switch required?  

* Add mechanical dimensions.

* Add duplicate BOOT, RESET button on the front side (?)

* Add silkscreen marking for TFT position.

* Change the Pico pin silkscreen labels to reflect the function of the pin in the analyzer design.

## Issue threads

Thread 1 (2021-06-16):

Link to legacy project links to self?

MarcelRobitaille, 2021-06-16:
The readme of this repo has a link to the "old" design, but it's a link to the repo itself. I think you mean to link to the legacy repo: https://github.com/zapta/legacy_stepper_motor_analyzer

zapta, 2021-06-16:
Thanks for letting me know. Fixed.

zapta, 2021-06-16:
Thanks. I replaced the broken BOM link with a link to the JLCPCB production files (gerbers and files for their SMD assembly service). The Pico, current sensors, and stepper motor connectors are not included since I solder them manually.

I hope to fine time to write more details assembly instructions, e.g. cutting the stepper motor connector pins to the right length using the 3D printed jig.

Regardless, building this design is easier than the previous one IMO.

MarcelRobitaille, 2021-06-16:
I already bought the old one. That's why I was looking for the legacy link. Thought I'd point out the BOM too. Thanks for making this. It's an awesome project.

zapta, 2021-06-16:
The old and the new designs have exactly the same capabilities so
should work for you. Make sure to pull up the RD pin of the TFT header
to +3.3v. That is missing from the PCB design and is covered by a note I
added later.

On Wed, Jun 16, 2021 at 10:51 AM Marcel Robitaille ***@***.***>
wrote:

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

zapta, 2021-06-17:
Added BOM file.

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

Closed 2022-08-10.

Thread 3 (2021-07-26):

Placement file issue reported by JLCPB

coelholm, 2021-07-26:
I have ordered the PCB from JLCPCB using production files from https://github.com/zapta/simple_stepper_motor_analyzer/tree/main/kicad/JLCPCB

They found placement minor issues with FPC1 and FPC2. From pictures looks like FPC1 is flipped horizontally, but I couldn't figure out any correction of FPC2.

It was corrected by JLCPCB before production, but I would like to let you know.

coelholm, 2021-07-26:
Original Placement:
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
&nbsp;
Adjusted Placement:
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

coelholm, 2021-07-26:
I will update you once it arrive and I have chance to test it.

zapta, 2021-07-26:
This is exactly what happened with my order but I verified their correction
and it seemed ok and when the boards worked with no problem.

I presume that they use the footprints from Easy EDA where they have
different center and orientation then the Kicad footprints I used.

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

zapta, 2021-07-26:
BTW, two assembly hints:

1. I recommend this 10mm double side tape. I use it for the Pico, avoid it
touching the main PCB, and for the TFT.  Available also from Aliexpress and
other sites.

https://www.amazon.com/gp/product/B072JJD2ND

2. Check the 3D directory for the STL file of the 3D printed connector jig.
I use it to cut the stepper connectors pins to the right side, keeping the
TFT side of the PCB flat.

3. I recently added a 3D model for an enclosure that doesn't need heat set
threaded inserts. Easier to build and good enough.

4. For firmware binary I recommend using the one from the latest firmware
release. (unless you want to modify and compile yourself).

Please let me know if you encounter any issues.

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

coelholm, 2021-07-29:
Thank you for those hints. I've order that tape and for sure that guide will help to cut connector.

zapta, 2021-07-29:
Please see if you can get from JLCPCB the corrected placement file and then
send me a pull request so others will not have to go through this confusion.

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

coelholm, 2021-07-29:
I've just tried with JLCPCB support to get that file without success. They said it is not possible to generate or provide details of adjusts made in their internal system, so I decided to spend some time trying to figure out by my self.

Looks like issue was related to FPC1 (Position and rotation: 51.3,28.85,-90 ) and Q1 (Rotation only: -90)

`
Designator,Val,Package,Mid X,Mid Y,Rotation,Layer

C1,100nf,SMD 0805,87.16,46.468,0,top
C2,100nf,SMD 0805,52.226,46.849,0,top
C3,10u,SMD 0805,44.06,47,90,top
FPC1,"FPC connector 40pins,  0.5mm,  TOP contacts",FH12-40S-0.5SH_1x40-1MP_P0.50mm_Horizontal_flipped,51.3,28.85,-90,top
FPC2,"FPC connector, 6 pins, 0.5mm, BOTTOM contacts",FH12-6S-0.5SH_1x06-1MP_P0.50mm_Horizontal,72.68,35.93,90,top
Q1,AO3400A ,SOT-23,42.964,8.622,-90,top
R1,8.2 Ohm,SMD 0805,40.424,13.448,90,top
R2,8.2 Ohm,SMD 0805,42.964,13.448,90,top
R3,8.2 Ohm,SMD 0805,45.504,13.448,90,top
`

coelholm, 2021-07-29:
Those screenshots are from JLCPCB "Review Parts Placement" tool.  Looks like it works after when you zoom in PCB, "< Go back" at the bottom of the page and then "NEXT" to get back to preview.

FPC1
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

Q1
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

coelholm, 2021-08-25:
Finally I have all parts, PCB and the time to assembly it.
I have assembled everything and update the firmware.

The LCD backlight is on, but it blank.  From serial I can see some messages, but I can't figure out what might be going on.

`dfsdfsf`
`0 0 0 0 0 0 0 0 0 0 0 0 0 0 0 0 0 0 0 0
0 0 0 0 0 0 0 0 0 0 0 0 0 0 0 0 0 0 0 0
[1500160][er:0, 0] [   -9,   -25] [en:0 0] s:2/0  steps:0 max_steps:0
DMA counters: 4394, 4394, 0

Free memory: 49127
Options: [DEFAULT]
Pico SDK version: 1.1.2.WizIO

total_size=32768, free_cnt=3, free_size=7128, free_bigest_size=6988
used_cnt=818, max_used=26124, used_pct=79, frag_pct=2

0 0 0 0 0 0 0 0 0 0 0 0 0 0 0 0 0 0 0 0
0 0 0 0 0 0 0 0 0 0 0 0 0 0 0 0 0 0 0 0
[1500160][er:0, 0] [  -12,   -26] [en:0 0] s:2/0  steps:0 max_steps:0
DMA counters: 5860, 5859, 0

Free memory: 49127
Options: [DEFAULT]
Pico SDK version: 1.1.2.WizIO

total_size=32768, free_cnt=3, free_size=7128, free_bigest_size=6988
used_cnt=818, max_used=26124, used_pct=79, frag_pct=2`

coelholm, 2021-08-27:
Hi @zapta,

I have ordered from the link you posted. So it should solve the problem. I appreciate your support. Thank you so much.

Just as a reference this is a basic example with initialization sequence for the R61529. [ESP32_LCD_MIPI_DBI_TYPE_B_TEST](https://github.com/daumemo/ESP32_LCD_MIPI_DBI_TYPE_B_TEST/blob/master/Arduino-Basic.cpp)

zapta, 2021-08-28:
Thanks coelholm.

I have a r61529 display and planned to write a driver for it but am busy
and can't see how I will get to it any time soon.

The plan was to have an alternative code for this ili9488 driver
https://github.com/zapta/simple_stepper_motor_analyzer/blob/main/platformio/src/display/tft_driver.cpp#L334.
Need also to see if the pinout is compatible and if the firmware can read
and detect which TFT is in use. Otherwise, it can be set during
assembly using the reserved 'options' jumper footprints on the PCB.

Anyway, please let me know if you will encounter any problem with the new
displays.

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

Closed 2021-08-27.

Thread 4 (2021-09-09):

Max step rate limitations

nightswimmer, 2021-09-09:
Hello. First of all, great project. Thank you for sharing. I'm now ordering the parts to build one. I play around with 3d printers and occasionally other projects involving steppers and this is just perfect. :)

WhiIe going through the specs I noticed you mention:
Max step rate | Software dependent. Currently 2K full steps/sec.

Does this mean it would be possible to increase this value? And if so, do you have an idea to how many? I imagine we can't go insanely high since we need a good amount of readings between steps so we can properly see the curves.

I'm very interested in this, since I am building a corexy 3d printer and will play around with high speeds and accelerations using 1.8º and 0.9º steppers. On a 0.9º stepper and with a common pulley type attached, 2000 steps is about 200mm/s. Considering the speeds people are printing things on corexy printers these days, this seems a little low.

JRHeaton, 2022-06-08:
Same here, would like to analyze 3d printer motors and feel that we need a higher bandwidth but am not familiar yet with the project enough to state any ideas on that. We may need a faster external clock, or different internal clock multipliers, or just a faster MCU.

zapta, 2022-06-08:
... The 100Khz analysis is done at full step level only, such that it's not
impacted by microstepping level (good) and doesn't affect the accuracy of
the fractional step display.

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

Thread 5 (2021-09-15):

Alternate for current sense module ACS70331EESATR-2P5B3?

pbinsted, 2021-09-15:
Does anyone have a source for these or an alternate that would work?

Edit - Sorry I had the wrong part. I believe the current PCB uses the ACS70331EOLCTR-2P5B3 which is the SOP-8 and appears to be available. Note this isn't listed in the current bom.

zapta, 2021-09-15:
Have you tried https://www.aliexpress.com/item/4001123087424.html ?

On Wed, Sep 15, 2021 at 7:23 AM Pete Binsted ***@***.***>
wrote:

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

pbinsted, 2021-09-15:
Thanks so much, I believe that's exactly what I ordered. And thanks so much for the great project.

Closed 2021-09-15.

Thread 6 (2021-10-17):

missing parts

legend069, 2021-10-17:
hello i tried to make this, but it seems i'm missing the two black chips(unsure of what part number)
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

can you let me know what they are so i can order solder on?

thanks.

zapta, 2021-10-17:
I got them from this Aliexpress vendor. The price went up three times now
due to the global semiconductor shortage but still available

https://www.aliexpress.com/item/4001123087424.html

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

globalcitizen, 2022-04-23:
The price is going up because the part **ACS70331EOLCTR-2P5B3** is discontinued. The design needs to be updated to use a current sensing approach that does not rely on discontinued parts.

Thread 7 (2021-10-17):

BOM is missing.

pinae, 2021-10-17:
README.md contains a link to a spreadsheet with the BOM: https://github.com/zapta/simple_stepper_motor_analyzer/blob/main/kicad/BOM.xlsx
This file does not exist.

Please add some information on which parts one needs to order. I understand that the files for JLPCB contain a list of components which get soldered on by the manufacturer. Are there additional components I need to buy apart from that? The FAQ mentions a Aliexpress-Link for the display without specifying which variant to order. Thereaded inserts are also mentioned but without further explanation.

zapta, 2021-10-17:
This may be the deleted BOM file. Please see if it helps you

https://github.com/zapta/simple_stepper_motor_analyzer/blob/81e511556d2a2a73e424c4d684bd37060a49d0eb/kicad/BOM.xlsx

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

Closed 2021-10-18.

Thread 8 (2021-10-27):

BOM link 404s.

JRHeaton, 2021-10-27:
Hi, I am not able to find a BOM as the link in the readme is broken. If it was deleted would the author be willing to reupload it and verify it’s contents? I am wanting to build a few of these for my employees and want to avoid wasting money on wrong parts or time on missing parts.

Thanks very much I look forward to hopefully hearing from you and being able to build this great tool.

Closed 2022-03-03.

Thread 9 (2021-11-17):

current sensor orientation

legend069, 2021-11-17:
hi, almost finished this neat project, just need to solder on the current sensors.
it's hard to tell by looking at the photos what orientation  i need to solder the current sensors.
can you please assist.

thanks.

globalcitizen, 2022-04-23:
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

According to current kicad sources, pin 1 should be to top right in both cases. This is indicated by the silkscreen circle on the current revision of the PCB in the kicad sources. Unsure if that's the same version you used.

If unsure, double-check the opposite pin (pin 5 = other side of IC and other end of IC) should have a via to GND.

zapta, 2022-04-23:
Yes, both dots are upper right in that orientation.

https://i.imgur.com/kfjeOYc.png

On Fri, Apr 22, 2022 at 6:15 PM Walter Stanish ***@***.***>
wrote:

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

Closed 2022-10-13.

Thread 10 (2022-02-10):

Question about ADC reading and code structure.

AndyEveritt, 2022-02-10:
I can not currently source the ACS70331EOLCTR-2P5B3 current sensors so I have been looking for alternatives.

I found this sensor from TI https://www.ti.com/lit/ds/symlink/tmcs1101-q1.pdf?HQS=dis-dk-null-mousermode-dsf-pf-null-wwe&ts=1641839042153 which seems to be approximately the same, but the sensitivity for the 3.3V version only goes up to 200mV/A (instead of 400mV/A).

To make sure that I could change the source code to accept this sensor I looked for where the sensitivity and and current range is set. Potentially I am misunderstanding but the datasheet for the current sensor says its +/-2.5A with 400mV/A and 1.5V at 0A.
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

In the code `src/misc/hardware_config.h`, the sensor struct appears to be defined
```cpp
struct SensorSpec {
  const char* name;
  const uint16_t range_milliamps;
  const float volts_per_amp;
  // These computed values are cached to speed up unit conversions.
  const float counts_per_amp;
  const float amps_per_count;
  const float milliamps_per_count;

  SensorSpec(const char* name_, uint16_t range_milliamps_, float volts_per_amp_)
      : name(name_),
        range_milliamps(range_milliamps_),
        volts_per_amp(volts_per_amp_),
        counts_per_amp(volts_per_amp * 4096 / 3.3),
        amps_per_count(1 / counts_per_amp),
        milliamps_per_count(1000 / counts_per_amp) {}

  // Convert adc value to milliamps.
  int adc_value_to_milliamps(int adc_value) const {
    return (int)(adc_value * milliamps_per_count);
  }

  // Convert adc value to amps.
  float adc_value_to_amps(int adc_value) const {
    return ((float)adc_value) * amps_per_count;
  }
};
```

As far as I can tell the conversion of adc value to (milli)amps does not take into account the 1.5V @ 0A offset that the sensor has?

For example, you create an instance of this struct using `static const SensorSpec GMR_2P5_SENSOR("G2P5A", 2500, 0.4);`. If the sensor was measuring 0A, it would output 1.5V, I believe this would read 2048 on the ADC (if you are using the an external 3.0V shunt reference for the ADC_VREF pin to improve ADC performance, which I can't see in the schematic either so might be a nice addition? Otherwise it will read ~1862).

Having just gone even deeper into trying to understand the code, I have now found that there is an offset for each of the ADC's in `src/aquisition/analyzer.h` which is applied to the value before it is converted to (milli)amps, which answers my question about if the sensor offset was being accounted for.

My new question (based on trying to get more familiar with embedded programming by learning from others) is why have you split the offset and other current sensor specific variables across 2 structs? I assume it is because the offset varies sensor to sensor so you need to calibrate it dynamically which would mean you couldn't use `const` for the sensor definition, which I assume is for some minor speed gain?

I appoligse for the long and convoluted question. I started typing as I was discovering to keep track of my train of thought. In essence, I would just like to understand why you have structured the code the way you have so I can learn and either apply or avoid it in my own coding.

Also it may be interesting to apply the recommended change to the circuit to improve the ADC performance
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

globalcitizen, 2022-04-23:
The TI part is __hall effect__ based. The originally specified part was __GMR__. There are also __TMR__ parts. [This paper explains the differences](https://crocus-technology.com/wp-content/uploads/2019/03/AN117-From-Hall-Effect-to-TMR-Rev0.1.pdf).

Based on that, maybe it would be best to look for TMR parts and [these guys](https://www.sinomags.com/En.html) seem promising.

zapta, 2022-04-23:
In another forum, somebody suggested this one
https://www.mouser.it/ProductDetail/ACEINNA/MCA1101-5-3?qs=PzGy0jfpSMs%252BNw%2FnqBFIdA%3D%3D
.  May require configuration tweaks because it has a different A/V
sensitivity.

It's difficult to find parts these days.

On Fri, Apr 22, 2022 at 6:43 PM Walter Stanish ***@***.***>
wrote:

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

globalcitizen, 2022-04-23:
Yep. __MCA1101-5-3__ is AMR based, according to [the datasheet](https://www.mouser.it/datasheet/2/940/6020-1104-01_B_Datasheet_2c_Current_Sensor_Fix_Gai-1622847.pdf). This 2015 review ([part one](http://magnetism.eu/esm/2015/slides/tiusan-slides1.pdf), [part two](http://magnetism.eu/esm/2015/slides/tiusan-slides2.pdf) compares AMR to the other approaches in more quantum physical detail than my mathematical literacy will stand for. But the result seems to be: if it's not TMR, it's functionally prior-generation and therefore potentially not the best thing to design for in terms of design longevity.

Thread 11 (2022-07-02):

display not powering up

yoc1983, 2022-07-02:
I soldered anything as said.
plugged the display connectors.
burn the firmware.
now I am plugging the pico USB to a power source.
the pico LED is blinking but the screen is not powering up
please any suggestion how to troubleshoot..

yoc1983, 2022-07-03:
ok i think i found the source for this
it seems the 40 pin connector JLCPCB soldered is wrong
looks like they soldered a bottom contact and it needs to be a top contact

zapta, 2022-07-03:
I am glad that you identify the problem.

IIRC when connected to a computer, the pico acts as a serial device and
prints some information. You can try running an terminal program on your
computer and see if it's live and performing measurements.

Also, if you want to test the display before you actually change the
connectors, you can try using an adapter like the one below with a PFC
cable that fix the top/bottom connectivity.

https://www.aliexpress.com/item/2251832590540738.html

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

yoc1983, 2022-07-03:
thanks I'm pretty sure it's the connector see in photo the connector they put against what's show on the product page
[https://drive.google.com/file/d/1bavQEIo6xxDr8_xo8EGmzUrYf8P3HNyD/view?usp=sharing](url)
also see in picture adapter from link is the same as what they put
so it might be also bottom contact.
and i hooked it to a terminal.. please see picture.. seems legit?
[https://drive.google.com/file/d/1LTrXf8-GXnUezjHyy1qDBUo8GET5GGag/view?usp=sharing](url)

zapta, 2022-07-05:
It's difficult to see in the picture if your connector is top or bottom
contact. The ones I have on my analyzer, as assembled by JLCPCB, are top
contacts.  The JLCPCB part number in the BOM and the one I got is  C11097
whose page is here
https://jlcpcb.com/parts/componentSearch?isSearch=true&searchTxt=C11097 and
it's datasheet indicates it's a top contact   [image: image.png]

As for your terminal output, it looks good, mentioning steps count and
such, so it seems to be live.

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

yoc1983, 2022-08-02:
@zapta
so as suggested i connected with the PCB that arrived from aliexpress see here:
[https://drive.google.com/file/d/1A5Pc9cYIGwl52zetmW0Yf0FD_EXcDvRH/view?usp=sharing](url)
now the screen shows half white and help weird stuff, see here:
[https://drive.google.com/file/d/1bptpH4T1mVB36qYaB8jWqCJk5nCJy8TP/view?usp=sharing](url)
any suggestion how to progress from here?

legend069, 2023-02-05:
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

> @zapta so as suggested i connected with the PCB that arrived from aliexpress see here: [https://drive.google.com/file/d/1A5Pc9cYIGwl52zetmW0Yf0FD_EXcDvRH/view?usp=sharing](url) now the screen shows half white and help weird stuff, see here: [https://drive.google.com/file/d/1bptpH4T1mVB36qYaB8jWqCJk5nCJy8TP/view?usp=sharing](url) any suggestion how to progress from here?

i'm gonna guess the screen died from when it was plugged in backwards.
it's that or the cable/pcb died.

zapta, 2023-02-16:
It's hard to tell what the problem is but I would check the large display
connector. Make sure the cable is inserted correctly and that there are no
visible shorts between the connector pins (some pins are supposed
tobe shorted by PCB traces per the schematic).

Also, can you post here a link to the TFT that you ordered?  I want to see
if it's the right kind.

BTW, I am finalizing a design that will eliminate the complexities around
the display. It iss a version that transmits the data in real time via
Bluetooth to a python app that displays it on a computer screen. Parts were
selected such that JLCPCB can also assemble all the components ($100 for 5
units, $350 for 30 units). I hope to release it in a few weeks.

https://imgur.com/a/fBPWIQX

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

zapta, 2023-02-16:
... the Bluetooth version can also be left within the printer and you can
connect to it from a computer any time you want.

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

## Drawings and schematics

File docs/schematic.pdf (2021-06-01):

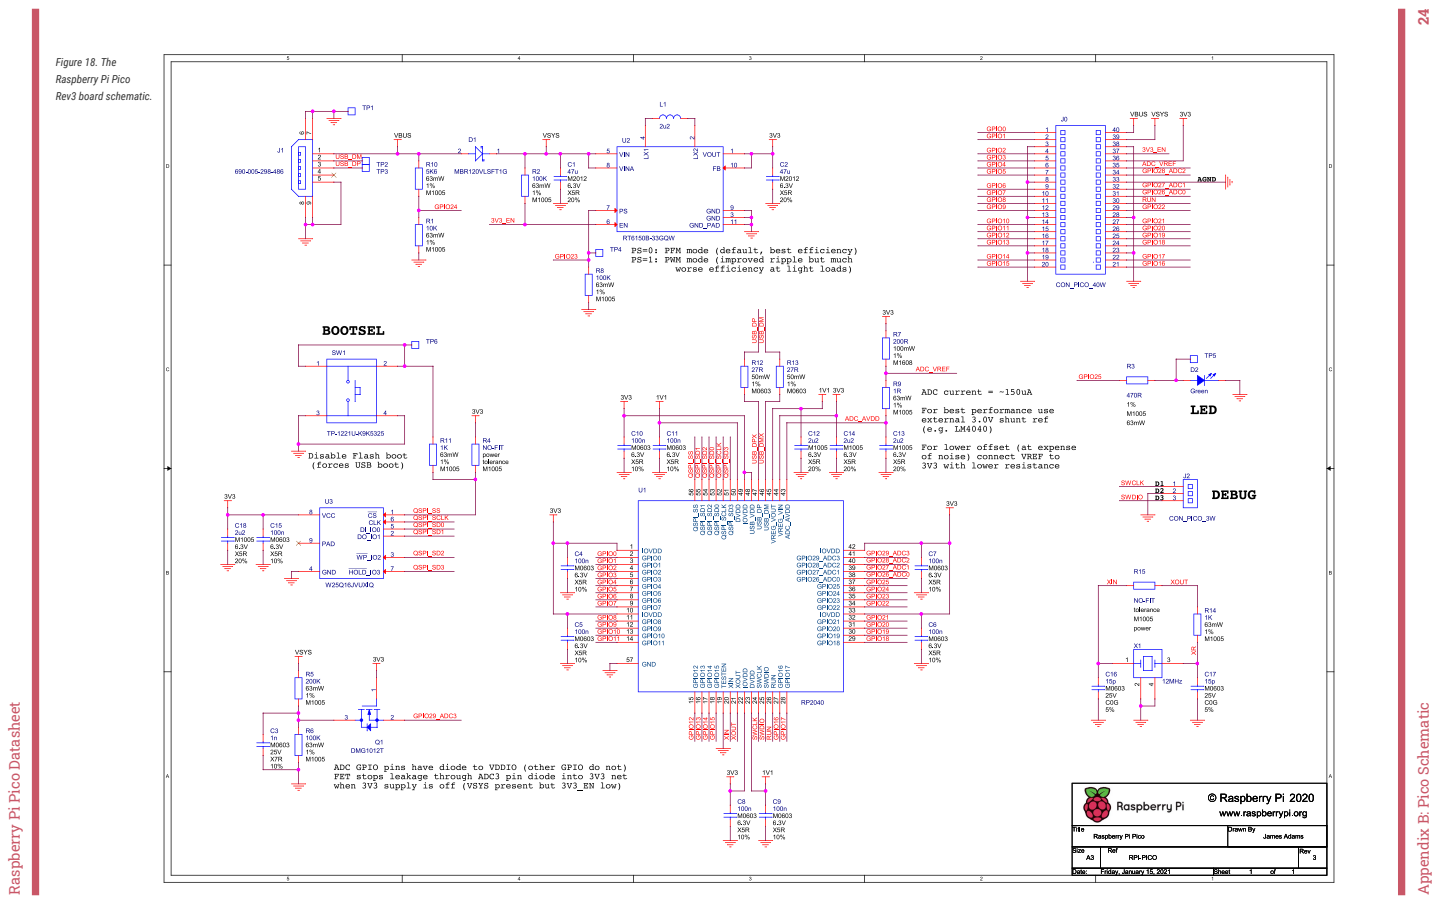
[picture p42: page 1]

Appendix B: Pico Schematic 24 24

Figure 18. The
Raspberry Pi Pico
Rev3 board schematic.

Raspberry Pi Pico Datasheet

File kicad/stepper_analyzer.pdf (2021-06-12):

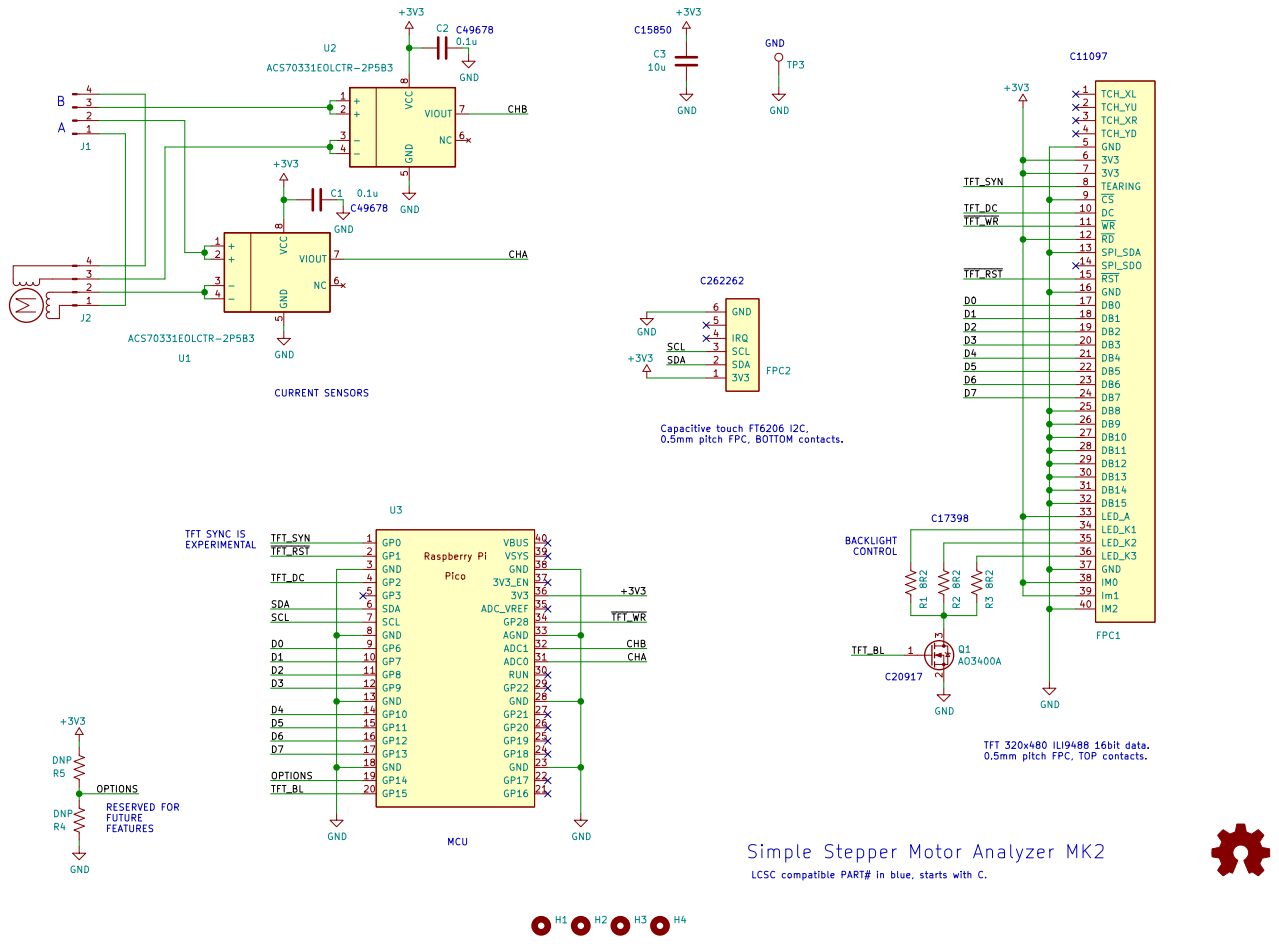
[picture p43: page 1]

0.5mm pitch FPC, BOTTOM contacts. MCU

LCSC compatible PART# in blue, starts with C.

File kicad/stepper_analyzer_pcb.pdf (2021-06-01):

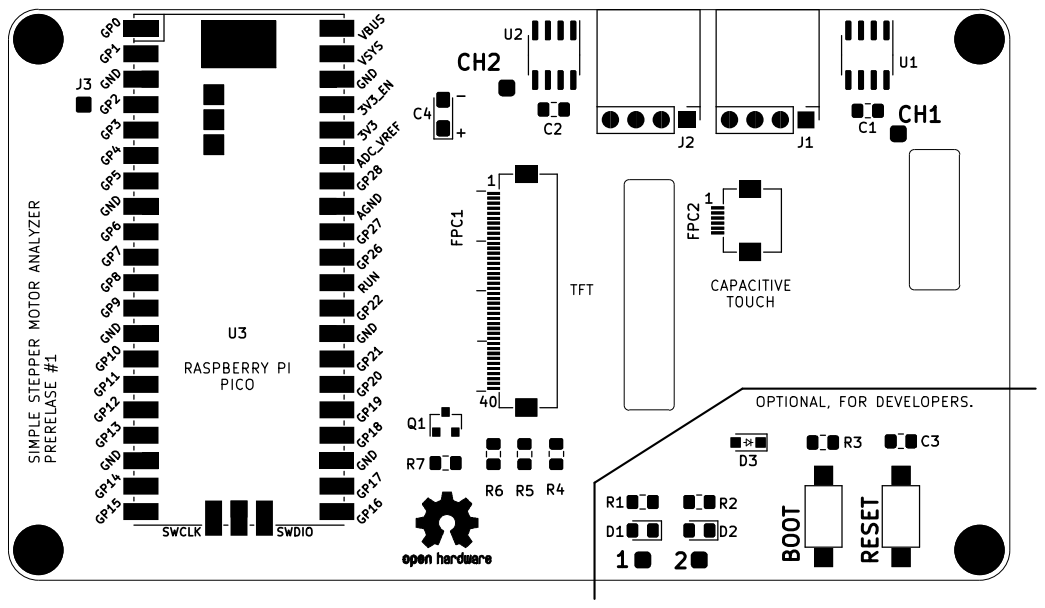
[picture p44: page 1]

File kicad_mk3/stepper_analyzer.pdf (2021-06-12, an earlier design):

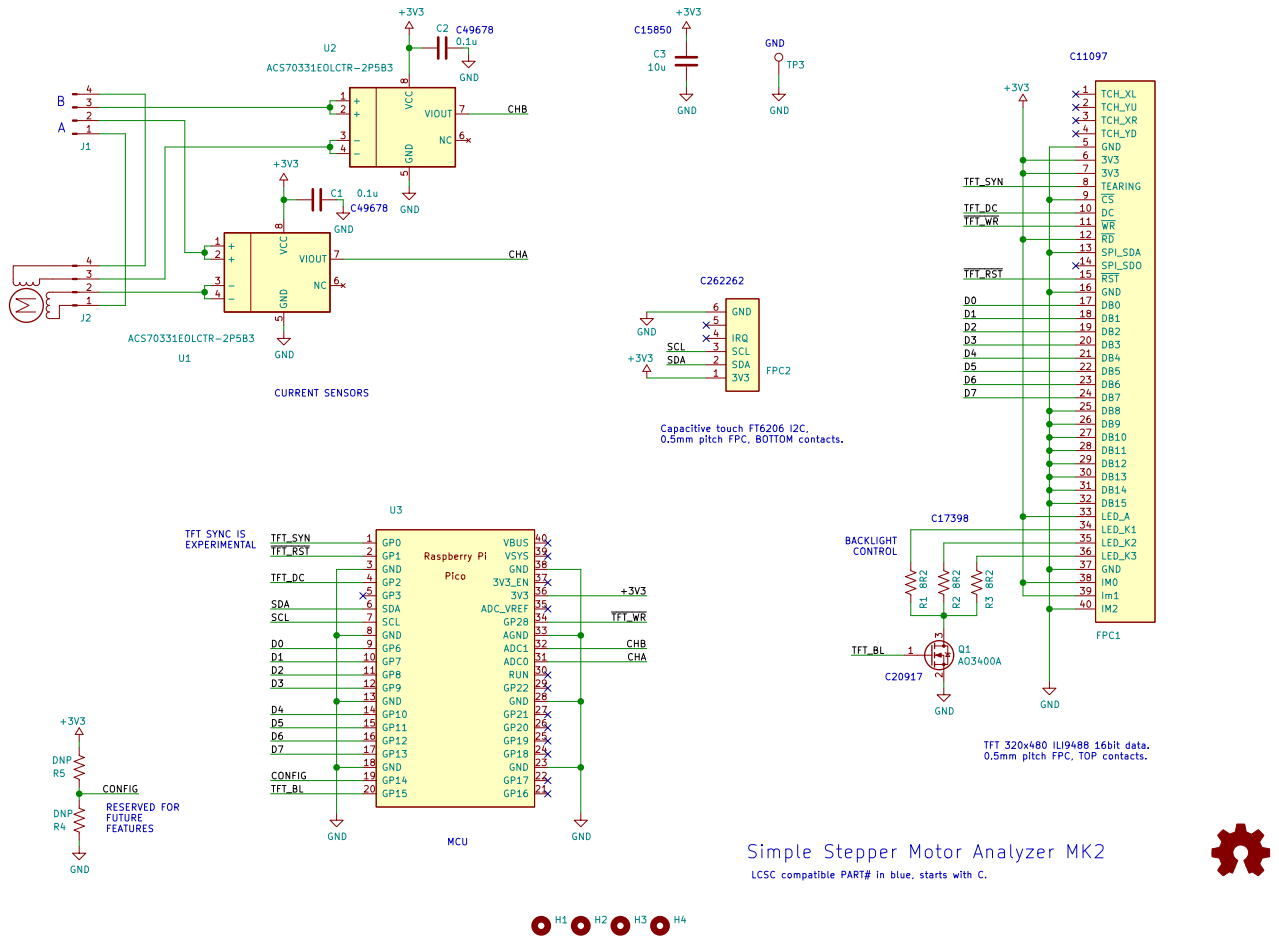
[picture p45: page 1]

0.5mm pitch FPC, BOTTOM contacts. MCU

LCSC compatible PART# in blue, starts with C.

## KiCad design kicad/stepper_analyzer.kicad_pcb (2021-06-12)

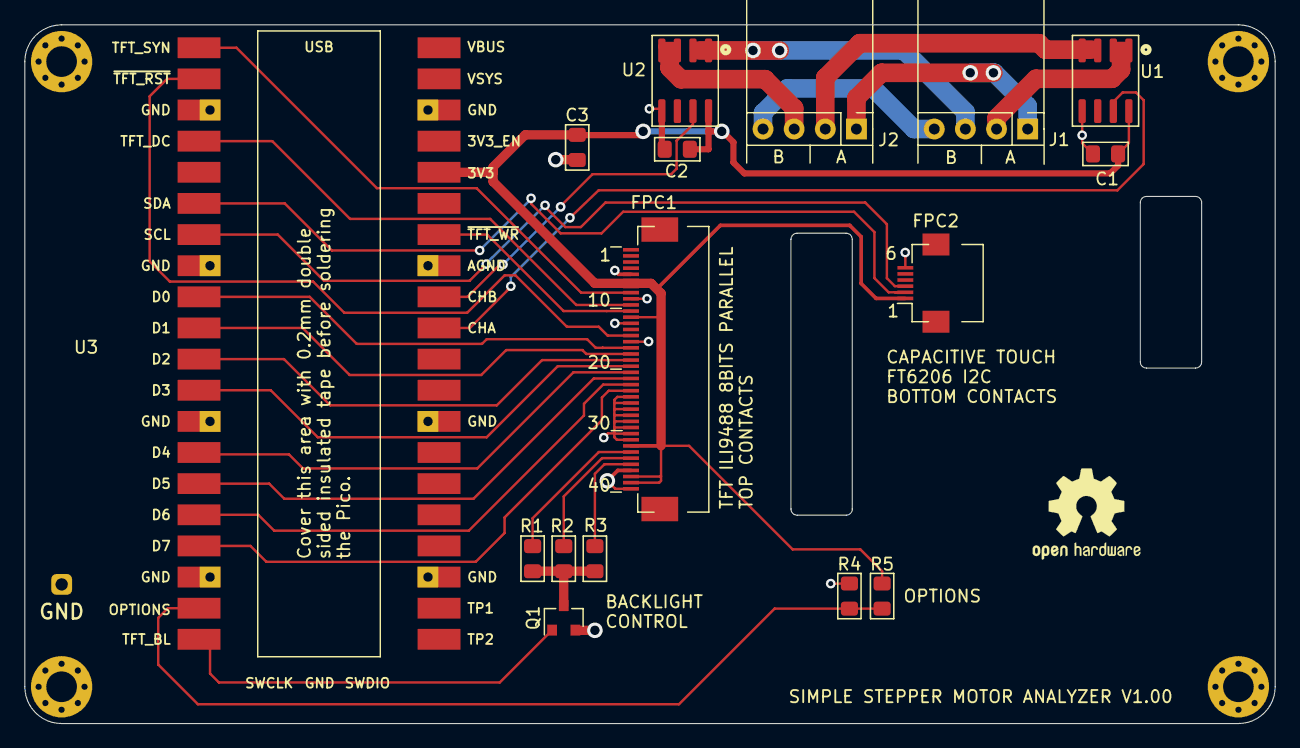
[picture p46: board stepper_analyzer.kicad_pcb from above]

Board: 2 copper layers, 102.0 x 57.0 mm, 23 parts (1 on the bottom side), 30 nets.

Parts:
C1, C2: 0.1u; C_0805_2012Metric_Pad1.15x1.40mm_HandSolder
C3: 10u; C_0805_2012Metric_Pad1.15x1.40mm_HandSolder
FPC1: Connector_Conn_01x40_Female; JUSHUO-AFC07-S40ECC-00_40P_05mm_flipped
FPC2: FPC connector, 6 pins, 0.5mm, BOTTOM contacts; JUSHUO-AFC01-S06FCC-00_6p_05mm
H1, H2, H3, H4: MountingHole; MountingHole_2.5mm_Pad_Via
J1, J2: Connector_Conn_01x04_Male; connector_4pins_horizontal
LOGO1: Logo_Open_Hardware_Small; OSHW-Logo2_9.8x8mm_SilkScreen
M1: Motor; null_footprint
Q1: AO3400A; SOT-23
R1, R2, R3: 8R2; R_0805_2012Metric_Pad1.15x1.40mm_HandSolder
R4, R5: DNP; R_0805_2012Metric_Pad1.15x1.40mm_HandSolder_no_3d
TP3: TestPoint; testpoint_double_side
U1, U2: ACS70331EOLCTR-2P5B3; SOIC-8_3.9x4.9mm_P1.27mm
U3: Pico; Pico_smd_dedicated

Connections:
+3V3: C1.2, C2.2, C3.2, FPC1.6, FPC1.7, FPC1.12, FPC1.33, FPC1.38, FPC1.39, FPC2.1, R5.2, U1.8, U2.8, U3.36
/CHA: U1.7, U3.31
/CHB: U2.7, U3.32
/D0: FPC1.17, U3.9
/D1: FPC1.18, U3.10
/D2: FPC1.19, U3.11
/D3: FPC1.20, U3.12
/D4: FPC1.21, U3.14
/D5: FPC1.22, U3.15
/D6: FPC1.23, U3.16
/D7: FPC1.24, U3.17
/OPTIONS: R4.1, R5.1, U3.19
/SCL: FPC2.3, U3.7
/SDA: FPC2.2, U3.6
/TFT_BL: Q1.1, U3.20
/TFT_DC: FPC1.10, U3.4
/TFT_SYN: FPC1.8, U3.1
/~TFT_RST: FPC1.15, U3.2
/~TFT_WR: FPC1.11, U3.34
GND: C1.1, C2.1, C3.1, FPC1.5, FPC1.9, FPC1.13, FPC1.16, FPC1.25, FPC1.26, FPC1.27, FPC1.28, FPC1.29, FPC1.30, FPC1.31, FPC1.32, FPC1.37, FPC1.40, FPC2.6, Q1.2, R4.2, TP3.1, U1.5, U2.5, U3.3, U3.8, U3.13, U3.18, U3.23, U3.28, U3.33, U3.38
unnamed: FPC1.34, R1.2
unnamed: FPC1.35, R2.2
unnamed: FPC1.36, R3.2
unnamed: J1.1, J2.1
unnamed: J1.2, U1.1, U1.2
unnamed: J1.3, U2.1, U2.2
unnamed: J1.4, J2.4
unnamed: J2.2, U1.3, U1.4
unnamed: J2.3, U2.3, U2.4
unnamed: Q1.3, R1.1, R2.1, R3.1

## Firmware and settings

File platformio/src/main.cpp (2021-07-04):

#include <stdio.h>

#include "acquisition/adc_dma.h"
#include "acquisition/analyzer.h"
#include "display/lvgl_adapter.h"
#include "display/tft_driver.h"
#include "display/touch_driver.h"
#include "io.h"
#include "lvgl.h"
#include "misc/config_eeprom.h"
#include "misc/elapsed.h"
#include "misc/hardware_config.h"
#include "misc/memory.h"
#include "pico/stdlib.h"
#include "ui/screen_manager.h"

constexpr uint8_t kColor8Blue = 0x3;

// TODO: move the lvgl tick timer to the lv_adapter file.

static Elapsed elapsed_from_last_dump;

static repeating_timer_t lvgl_ticker;

// LVGL time ticks IRQ.
static bool timer_callback(repeating_timer_t* rt) {
  lv_tick_inc(5);
  return true;  // keep repeating
}

static Elapsed timer;

void setup() {
  stdio_init_all();
  hardware_config::determine();

  io::setup();

  LED0_ON;

  // TODO: Read settings from EEPROM
  analyzer::Settings acq_settings;
  uint8_t backlight_percents;
  config_eeprom::read_settings(&acq_settings, &backlight_percents);

  // Must setup analyzer before adc_dma.
  analyzer::setup(acq_settings);
  adc_dma::setup();

  touch_driver::setup();

  // ver.begin();

  lvgl_adapter::setup();

  analyzer::reset_state();

  screen_manager::setup();

  const bool timer_ok =
      add_repeating_timer_ms(5, timer_callback, NULL, &lvgl_ticker);

  // Render the first page.
  // lv_task_handler();
  screen_manager::loop();
  lv_refr_now(NULL);
  sleep_ms(30);  // let the screen process the data to avoid initial flicker.

  // Turn on the backlight. User can now see the screen.
  lvgl_adapter::set_backlight(backlight_percents);
  // millis_to_first_screen = to_ms_since_boot(get_absolute_time());

  // Now that the first screen is display. We can spend some
  // time setting up proactivly the other screens. Otherwise
  // they will be setup on demand on first invocation.
  screen_manager::setup_screens_ahead();
}

void loop() {
  // LVGL processing and rendering.
  lv_task_handler();

  // Screen updates.
  screen_manager::loop();

  // Heartbeat.
  if (to_ms_since_boot(get_absolute_time()) % 1000 < 50) {
    LED0_ON;
  } else {
    LED0_OFF;
  }

  // Periodic report over USB/Serial. For debugging.
  if (elapsed_from_last_dump.elapsed_millis() > 3000) {
    elapsed_from_last_dump.reset();

    static uint print_cycle = 0;

    switch (print_cycle) {
      default:
      case 0:
        printf("\nFree memory: %d\n", memory::free_memory());
        printf("Config: [%s] [%s]\n", hardware_config::level_name(),
               hardware_config::sensor_name());
        puts("Pico SDK version: " PICO_SDK_VERSION_STRING);
        print_cycle = 1;
        break;
      case 1:
        printf("\n");
        lvgl_adapter::dump_stats();
        print_cycle = 2;
        break;
      case 2:
        printf("\n");
        analyzer::sample_state();
        analyzer::dump_sampled_state();
        adc_dma::dump_state();
        print_cycle = 0;
        break;
    }
  }
}

// Arduino like main.
int main() {
  setup();
  for (;;) {
    loop();
  }
}

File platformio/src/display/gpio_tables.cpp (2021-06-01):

#include "gpio_tables.h"

// Tables were generated using the gpio_tables_generator.py script.

namespace gpio_tables {

// PIN MAP:
//   WR     1
//
//   D0    28
//   D1     3
//   D2     6
//   D3     7
//   D4     8
//   D5     9
//   D6    22
//   D7    10
//   D8    11
//   D9    21
//   D10   12
//   D11   20
//   D12   13
//   D13   19
//   D14   14
//   D15   18

const uint32_t gpio_direct_set_table[] = {
    0x00000000, 0x10000000, 0x00000008, 0x10000008,  // 0x00 - 0x03
    0x00000040, 0x10000040, 0x00000048, 0x10000048,  // 0x04 - 0x07
    0x00000080, 0x10000080, 0x00000088, 0x10000088,  // 0x08 - 0x0b
    0x000000c0, 0x100000c0, 0x000000c8, 0x100000c8,  // 0x0c - 0x0f
    0x00000100, 0x10000100, 0x00000108, 0x10000108,  // 0x10 - 0x13
    0x00000140, 0x10000140, 0x00000148, 0x10000148,  // 0x14 - 0x17
    0x00000180, 0x10000180, 0x00000188, 0x10000188,  // 0x18 - 0x1b
    0x000001c0, 0x100001c0, 0x000001c8, 0x100001c8,  // 0x1c - 0x1f
    0x00000200, 0x10000200, 0x00000208, 0x10000208,  // 0x20 - 0x23
    0x00000240, 0x10000240, 0x00000248, 0x10000248,  // 0x24 - 0x27
    0x00000280, 0x10000280, 0x00000288, 0x10000288,  // 0x28 - 0x2b
    0x000002c0, 0x100002c0, 0x000002c8, 0x100002c8,  // 0x2c - 0x2f
    0x00000300, 0x10000300, 0x00000308, 0x10000308,  // 0x30 - 0x33
    0x00000340, 0x10000340, 0x00000348, 0x10000348,  // 0x34 - 0x37
    0x00000380, 0x10000380, 0x00000388, 0x10000388,  // 0x38 - 0x3b
    0x000003c0, 0x100003c0, 0x000003c8, 0x100003c8,  // 0x3c - 0x3f
    0x00400000, 0x10400000, 0x00400008, 0x10400008,  // 0x40 - 0x43
    0x00400040, 0x10400040, 0x00400048, 0x10400048,  // 0x44 - 0x47
    0x00400080, 0x10400080, 0x00400088, 0x10400088,  // 0x48 - 0x4b
    0x004000c0, 0x104000c0, 0x004000c8, 0x104000c8,  // 0x4c - 0x4f
    0x00400100, 0x10400100, 0x00400108, 0x10400108,  // 0x50 - 0x53
    0x00400140, 0x10400140, 0x00400148, 0x10400148,  // 0x54 - 0x57
    0x00400180, 0x10400180, 0x00400188, 0x10400188,  // 0x58 - 0x5b
    0x004001c0, 0x104001c0, 0x004001c8, 0x104001c8,  // 0x5c - 0x5f
    0x00400200, 0x10400200, 0x00400208, 0x10400208,  // 0x60 - 0x63
    0x00400240, 0x10400240, 0x00400248, 0x10400248,  // 0x64 - 0x67
    0x00400280, 0x10400280, 0x00400288, 0x10400288,  // 0x68 - 0x6b
    0x004002c0, 0x104002c0, 0x004002c8, 0x104002c8,  // 0x6c - 0x6f
    0x00400300, 0x10400300, 0x00400308, 0x10400308,  // 0x70 - 0x73
    0x00400340, 0x10400340, 0x00400348, 0x10400348,  // 0x74 - 0x77
    0x00400380, 0x10400380, 0x00400388, 0x10400388,  // 0x78 - 0x7b
    0x004003c0, 0x104003c0, 0x004003c8, 0x104003c8,  // 0x7c - 0x7f
    0x00000400, 0x10000400, 0x00000408, 0x10000408,  // 0x80 - 0x83
    0x00000440, 0x10000440, 0x00000448, 0x10000448,  // 0x84 - 0x87
    0x00000480, 0x10000480, 0x00000488, 0x10000488,  // 0x88 - 0x8b
    0x000004c0, 0x100004c0, 0x000004c8, 0x100004c8,  // 0x8c - 0x8f
    0x00000500, 0x10000500, 0x00000508, 0x10000508,  // 0x90 - 0x93
    0x00000540, 0x10000540, 0x00000548, 0x10000548,  // 0x94 - 0x97
    0x00000580, 0x10000580, 0x00000588, 0x10000588,  // 0x98 - 0x9b
    0x000005c0, 0x100005c0, 0x000005c8, 0x100005c8,  // 0x9c - 0x9f
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
};
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

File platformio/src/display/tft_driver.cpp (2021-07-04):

#include "tft_driver.h"

#include <stdio.h>
#include <stdlib.h>

#include "hardware/dma.h"
#include "hardware/gpio.h"
#include "hardware/irq.h"
#include "hardware/pio.h"
#include "hardware/pwm.h"
#include "io.h"
#include "pico/stdlib.h"
#include "tft_driver.pio.h"

namespace tft_driver {

// Plain GPIO output pins.
#define TFT_RST_PIN 1  // Active low.
#define TFT_DC_PIN 2   // 1: data, 0: command.
#define TFT_BL_PIN 15  // Active high

// Outputs managed by PioTft.
#define TFT_D0_PIN 6   // First of 8 data pins, [GPIO_6, GPIO_13]
#define TFT_WR_PIN 28  // Active low
// Added in MK4. Prior versions cannot read the TFT.
#define TFT_RD_PIN 22  // Active low

#define TFT_RST_HIGH gpio_set_mask(1ul << TFT_RST_PIN)
#define TFT_DC_HIGH gpio_set_mask(1ul << TFT_DC_PIN)

#define TFT_RST_LOW gpio_clr_mask(1ul << TFT_RST_PIN)
#define TFT_DC_LOW gpio_clr_mask(1ul << TFT_DC_PIN)

// // Assuming landscape mode per memory access command 0x36.
#define WIDTH 480
#define HEIGHT 320

#define ILI9488_SLPOUT 0x11

#define ILI9488_DISPON 0x29

#define ILI9488_CASET 0x2A
#define ILI9488_PASET 0x2B
#define ILI9488_RAMWR 0x2C
#define ILI9488_RAMRD 0x2E

// namespace tft_driver {

constexpr uint16_t PIO_CLOCK_DIV = 1;

#define PIO (pio0)
#define SM 0

// Masks for the FDEBUG register.
static constexpr uint32_t SM_STALL_MASK = 1u << (PIO_FDEBUG_TXSTALL_LSB + SM);
static constexpr uint32_t SM_OVERRUN_MASK = 1u << (PIO_FDEBUG_TXOVER_LSB + SM);

// Updated later with the loading offset of the PIO program.
static uint pio_program_offset = 0;

// Info about the PWM channel used for the backlight output.
static uint bl_pwm_slice_num;
static uint bl_pwm_channel;

static void pio_set_x(uint32_t v) {
  static const uint instr_shift = pio_encode_in(pio_x, 4);
  static const uint instr_mov = pio_encode_mov(pio_x, pio_isr);
  for (int i = 7; i >= 0; i--) {
    const uint32_t nibble = (v >> (i * 4)) & 0xf;
    pio_sm_exec(PIO, SM, pio_encode_set(pio_x, nibble));
    pio_sm_exec(PIO, SM, instr_shift);
  }
  pio_sm_exec(PIO, SM, instr_mov);
}

void set_backlight(uint8_t percents) {
  // Don't go beyond a minimum level to make sure some
  // display is visible.
  percents = MAX(5, percents);
  percents = MIN(100, percents);
  pwm_set_chan_level(bl_pwm_slice_num, bl_pwm_channel, percents);
}

// BL output is PWM driven.
static void init_pwm() {
  bl_pwm_slice_num = pwm_gpio_to_slice_num(TFT_BL_PIN);
  bl_pwm_channel = pwm_gpio_to_channel(TFT_BL_PIN);
  gpio_set_function(TFT_BL_PIN, GPIO_FUNC_PWM);
  pwm_set_wrap(bl_pwm_slice_num, 99);
  // Reduce PWM freq to ~4.8Khz
  pwm_set_clkdiv_int_frac(bl_pwm_slice_num, 255, 0);
  // We start with BL off.
  pwm_set_chan_level(bl_pwm_slice_num, bl_pwm_channel, 0);
  pwm_set_enabled(bl_pwm_slice_num, true);
}

static void init_gpio() {
  // A mask with all gpio output pins we use.
  constexpr uint kOutputMask = 1ul << TFT_RST_PIN | 1ul << TFT_DC_PIN;
  gpio_init_mask(kOutputMask);
  gpio_set_dir_out_masked(kOutputMask);
}

static void init_pio() {
  // Make sure nobody else uses this state machine.
  pio_sm_claim(PIO, SM);

  // Load the PIO program. Starting by default with 16 bits mode
  // since it's at the begining of the PIO program.
  pio_program_offset = pio_add_program(PIO, &tft_driver_pio_program);

  // Associate pins with the PIO.
  pio_gpio_init(PIO, TFT_WR_PIN);
  pio_gpio_init(PIO, TFT_RD_PIN);
  for (int i = 0; i < 8; i++) {
    pio_gpio_init(PIO, TFT_D0_PIN + i);
  }

  // Configure the pins to be outputs.
  pio_sm_set_consecutive_pindirs(PIO, SM, TFT_WR_PIN, 1, true);
  pio_sm_set_consecutive_pindirs(PIO, SM, TFT_RD_PIN, 1, true);
  // Initially outputs. The PIO program latter toggle these to be
  // input or output as needed.
  pio_sm_set_consecutive_pindirs(PIO, SM, TFT_D0_PIN, 8, true);

  // Configure the state machine.
  pio_sm_config c =
      tft_driver_pio_program_get_default_config(pio_program_offset);
  // The pio program declares that a single sideset pin is used.
  // Define it.
  sm_config_set_sideset_pins(&c, TFT_WR_PIN);
  sm_config_set_set_pins(&c, TFT_RD_PIN, 1);

  // The 8 consecutive pins that are used for data outout.
  sm_config_set_out_pins(&c, TFT_D0_PIN, 8);

  sm_config_set_in_pins(&c, TFT_D0_PIN);

  // Set clock divider. Value of 1 for max speed.
  sm_config_set_clkdiv_int_frac(&c, PIO_CLOCK_DIV, 0);

  // The OSR register shifts to the right, sending the MSB byte
  // first, in a double bytes transfers.
  sm_config_set_out_shift(&c, true, false, 0);
  sm_config_set_in_shift(&c, false, false, 0);
  // Set the SM with the configuration we constructed above.
  // Default mode is single byte.
  pio_sm_init(PIO, SM, pio_program_offset + tft_driver_pio_offset_start_wr8,
              &c);

  // Start the state machine.
  pio_sm_set_enabled(PIO, SM, true);
}

static void flush() {
  // Clear the sticky stall status.
  PIO->fdebug = SM_STALL_MASK;
  // Wait until the stall flag is up again.
  while (!(PIO->fdebug & SM_STALL_MASK)) {
  }

  const uint rx_count = pio_sm_get_rx_fifo_level(PIO, SM);
  const uint tx_count = pio_sm_get_tx_fifo_level(PIO, SM);
  if (rx_count || tx_count) {
    printf("WARNING: Dropping FIFOs, rx=%u, tx=%u\n", rx_count, tx_count);
  }
  pio_sm_clear_fifos(PIO, SM);
}

// TODO: consider to use the same init table for wr8 and wr16.
static const uint wr8_init_table[] = {
    0xf801,  // set    pins, 1         side 1
    0xe020,  // set    x, 0
    0xa0e9,  // mov    osr, !x
    0x6088,  // out    pindirs, 8
};

static void set_mode_write_8() {
  flush();

  pio_sm_set_enabled(PIO, SM, false);

  constexpr int N = sizeof(wr8_init_table) / sizeof(wr8_init_table[0]);
  for (int i = 0; i < N; i++) {
    pio_sm_exec(PIO, SM, wr8_init_table[i]);
  }

  // Force jump to start address.
  // pio_program_offset is a variable so can't be used in the static init table.
  pio_sm_exec(
      PIO, SM,
      pio_encode_jmp(pio_program_offset + tft_driver_pio_offset_start_wr8));

  pio_sm_set_enabled(PIO, SM, true);
}

static const uint wr16_init_table[] = {
    0xf801,  // set    pins, 1         side 1
    0xe020,  // set    x, 0
    0xa0e9,  // mov    osr, !x
    0x6088,  // out    pindirs, 8
};

static void set_mode_write_16() {
  flush();
  pio_sm_set_enabled(PIO, SM, false);

  constexpr int N = sizeof(wr16_init_table) / sizeof(wr16_init_table[0]);
  for (int i = 0; i < N; i++) {
    pio_sm_exec(PIO, SM, wr16_init_table[i]);
  }

  // Force jump to start address.
  // pio_program_offset is a variable so can't be used in the static init table.
  pio_sm_exec(
      PIO, SM,
      pio_encode_jmp(pio_program_offset + tft_driver_pio_offset_start_wr16));
  pio_sm_set_enabled(PIO, SM, true);
}

static const uint rd8_init_table[] = {
    0xf801,  // 18: set    pins, 1         side 1
    0xe040,  // 19: set    y, 0
    0xa0e2,  // 20: mov    osr, y
    0x6088,  // 21: out    pindirs, 8
};
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

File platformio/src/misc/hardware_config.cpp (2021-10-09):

#include "hardware_config.h"

#include "pico/stdlib.h"

namespace hardware_config {

constexpr uint8_t LEVELS_PIN = 21;
constexpr uint8_t SENSORS_PIN = 14;

// We use arbitrary values to make sure things do
// not break.
static const SensorSpec UNKNOWN_SENSOR("????", 2500, 0.4);

// ACS70331EOLCTR-2P5B3
static const SensorSpec GMR_2P5_SENSOR("G2P5A", 2500, 0.4);

// ACS712ELCTR-05B-T
// We limit the range to 3A since this is the
// most 3D printer use cases fall here.
//static SensorSpec HAUL_5A_SENSOR("H5A", 3000, 0.185);

static HardwareConfig hardware_config(LEVEL_UNKNOWN, &UNKNOWN_SENSOR);

enum PinState { STATE_ERROR, STATE_FLOAT, STATE_DOWN, STATE_UP };

static PinState determine_config_pin_state(uint pin) {
  gpio_init(pin);
  gpio_set_dir(pin, false);
  gpio_pull_down(pin);
  sleep_ms(10);
  const bool state_down = gpio_get(pin);
  gpio_pull_up(pin);
  sleep_ms(10);
  const bool state_up = gpio_get(pin);
  return state_up ? (state_down ? STATE_UP : STATE_FLOAT)
                  : (state_down ? STATE_ERROR : STATE_DOWN);
}

static Level determine_level() {
  const PinState pin_state = determine_config_pin_state(LEVELS_PIN);
  switch (pin_state) {
    case STATE_FLOAT:
      return LEVEL_MK3;
    case STATE_DOWN:
      return LEVEL_MK4;
    case STATE_UP:
      return LEVEL_MK5;
    default:
      return LEVEL_UNKNOWN;
  }
}

static const SensorSpec* determine_sensor() {
  const PinState pin_state = determine_config_pin_state(SENSORS_PIN);
  switch (pin_state) {
    case STATE_FLOAT:
      return &GMR_2P5_SENSOR;
    case STATE_DOWN:
      // Reserved for a future sernsor.
      return &UNKNOWN_SENSOR;
    case STATE_UP:
    default:
      return &UNKNOWN_SENSOR;
  }
}

HardwareConfig determine() {
  hardware_config = HardwareConfig(determine_level(), determine_sensor());
  return hardware_config;
}

const HardwareConfig& config() { return hardware_config; }

const char* level_name() {
  switch (hardware_config.level) {
    case LEVEL_MK3:
      return "MK3";
    case LEVEL_MK4:
      return "MK4";
    case LEVEL_MK5:
      return "MK5";
    default:
      return "UNKNOWN";
  }
}

}  // namespace hardware_config

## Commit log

2021-06-01 Initial set of files.
    [FH12-40S-0.5SH.stp, FPC 6-PIN SMD.stp, KMR211GLFS.step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]
2021-06-01 Updated documentation
    [BOM.xlsx]
2021-06-01 Switched the documentation
2021-06-01 Added 3D model
    [enclosure.stl]
2021-06-02 Fixed typos and added a skeleton lib directory.
    [settings_screen.cpp]
2021-06-07 Cleaned up the schematic. No semantic change.
    [stepper_analyzer.kicad_pcb, stepper_analyzer.sch]
2021-06-08 Refactored the tft driver to a class instance.
2021-06-09 Added a skeleton MK3 driver.
2021-06-09 Added TFT driver for MK3
2021-06-10 Updated kicad files for MK3
    [BOM.xlsx, stepper_analyzer.kicad_pcb, stepper_analyzer.sch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]
2021-06-10 Generated gerbers
    [stepper_analyzer.kicad_pcb]
2021-06-10 Remove orhpan text message.
    [stepper_analyzer.kicad_pcb]
2021-06-10 Regenerated gerbers.
2021-06-10 Updated label on the PCB.
    [stepper_analyzer.kicad_pcb, stepper_analyzer.sch]
2021-06-10 Updated schematic PDF.
    [stepper_analyzer.kicad_pcb]
2021-06-10 Regenerated gerbers
2021-06-10 Updated top silk text.
    [stepper_analyzer.kicad_pcb]
2021-06-10 Added missing FPC1 top silk reference.
    [stepper_analyzer.kicad_pcb]
2021-06-10 Remove A,B test points. Reduce bottom layer traces.
    [stepper_analyzer.kicad_pcb, stepper_analyzer.sch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]
2021-06-10 Updated schematic.
2021-06-10 Minor schematic tweaks.
    [stepper_analyzer.sch]
2021-06-10 Added stepper_analyzer-cache.lib to gitignore.
2021-06-10 Added stepper_motor_analyzer.bck to gitignore.
2021-06-10 Deleted stepper_analyzer.xml
2021-06-11 Renamed kicad directory to kicad_mk3
    [FH12-40S-0.5SH.stp, FPC 6-PIN SMD.stp, KMR211GLFS.step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]
2021-06-12 Added kicad files of mk2 (old hardware version). Taken from commit d4c36661691f7af347b63aa49380aba189a09ed7
    [BOM.xlsx, FH12-40S-0.5SH.stp, FPC 6-PIN SMD.stp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]
2021-06-12 Updated pin numbers.
2021-06-12 Tweaked TFT insulation.
    [stepper_analyzer.kicad_pcb, stepper_analyzer.sch]
2021-06-12 Cleaned up the +3.3V path.
    [stepper_analyzer.kicad_pcb]
2021-06-12 Updated pos file.
    [stepper_analyzer.kicad_pcb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]
2021-06-12 Added JLCB gerbers
2021-06-12 Changed 10u from tant to ceramic.
    [stepper_analyzer.kicad_pcb, stepper_analyzer.sch, stepper_analyzer_bom.csv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]
2021-06-12 Change config jumpers to resistors.
    [stepper_analyzer.kicad_pcb, stepper_analyzer.sch]
2021-06-12 Deleted kicad_mk2, renamed kicad_mk3 to kicad.
    [BOM.xlsx, FH12-40S-0.5SH.stp, FPC 6-PIN SMD.stp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]
2021-06-12 Fixed silkscreen on back side.
    [stepper_analyzer.kicad_pcb]
2021-06-12 Fixed a typo.
    [stepper_analyzer.kicad_pcb]
2021-06-12 Tweaked silk screen.
    [stepper_analyzer.kicad_pcb]
2021-06-12 Renamed Config to Options
    [stepper_analyzer.kicad_pcb, stepper_analyzer.sch]
2021-06-13 Updfated Kicad TODOs.
2021-06-13 Added print of the Pico SDK version.
2021-06-16 Fixed a broken BOM link.
2021-06-17 Added BOM file.
    [BOM.xlsx]
2021-06-18 Both ADC DMA channels now use IRQ0. Freed IRQ1 for future display update.
2021-06-19 Changed the tft driver to use DMA and double buffer (speedup).
2021-06-19 Improved the screenshot button.
2021-06-19 Missing rename from previous commit.
    [analyzer.h]
2021-06-19 Changed the steps screen to user hard timing for the samplings rather than relying on frame rate.
2021-06-19 Changed the retraction screen to use hard timing rather than relying on frame rate.
2021-06-20 Changed the speed gauge screen to use hard timing rather than relying on frame rate.
2021-06-20 Added PWM control of TFT backlight. Still not exposed to the user.
2021-06-21 Updated Kicad TODOs.
2021-06-24 Updated 3D model and kicad TODOs.
    [enclosure.stl]
2021-06-24 Updated kicad todo
2021-06-26 Added a Kicad TODO
2021-07-02 Changed the firmware to have the RD pin at 22 (was 18).
2021-07-03 Added support for current sensor configuration. Will allow to support different sensors.
2021-07-03 Made schematic and PCB changes toward MK3. Not ready.
    [stepper_analyzer.kicad_pcb, stepper_analyzer.sch]
2021-07-03 Teaked board design toward MK4.
    [stepper_analyzer.kicad_pcb, stepper_analyzer.sch]
2021-07-04 Split between the x and y axis configurations. Will allow to support dynmic sensor selection.
2021-07-04 Added a kicad TODO.
2021-07-04 Added per sensor type range selection.
2021-07-04 Added a warning regarding using official releases of kicad files.
2021-07-04 Updated kicad note
2021-07-04 Updated screen capture to direct TFT read. Requires hardware level MK4. Does not work on MK3.
    [main.cpp, tft_driver.cpp]
2021-07-04 Updated Kicad TODO.
2021-07-05 Added an enclosure version that doesn't need metal threaded heat inserts. Easier to source and build.
    [enclosure_metal_insert_threads.stl, enclosure_self_tapping_threads.stl]
2021-07-05 Assorted tweaks.
    [enclosure_self_tapping_threads.stl, stepper_analyzer.sch]
2021-07-12 Made the shcematic non-release warning more visible.
    [stepper_analyzer.sch]
2021-07-19 Updated enclosure 3D models to the latest in OnShape.
    [enclosure_metal_insert_threads.stl, enclosure_self_tapping_threads.stl]
2021-07-26 Resoted Kicad files to V1.00 release.
    [BOM.xlsx, stepper_analyzer.kicad_pcb, stepper_analyzer.sch]
2021-10-09 Set filtering of the second channel to 700 as well (was a typo) and removed the detection of the HAUL 5A which is not in use, reserving it to a future sensor.
2021-10-27 Added missing BOM file (deleted unintentionally in a previous commit)
    [BOM.csv, BOM.xlsx]
